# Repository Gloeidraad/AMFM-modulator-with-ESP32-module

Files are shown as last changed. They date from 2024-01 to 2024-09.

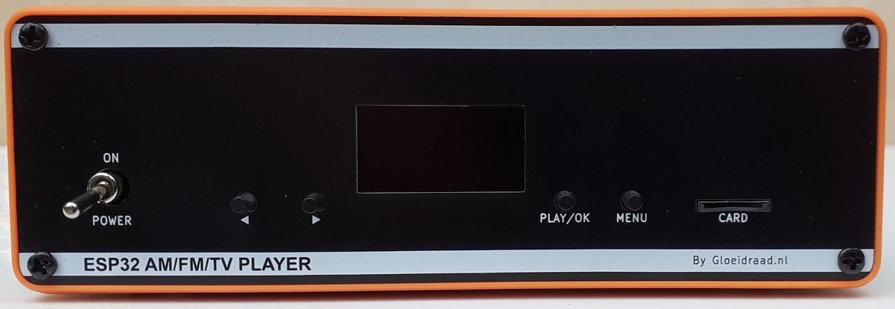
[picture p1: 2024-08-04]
V1.7/ASSY_1_7/3D-printables/Assembled 3.jpg

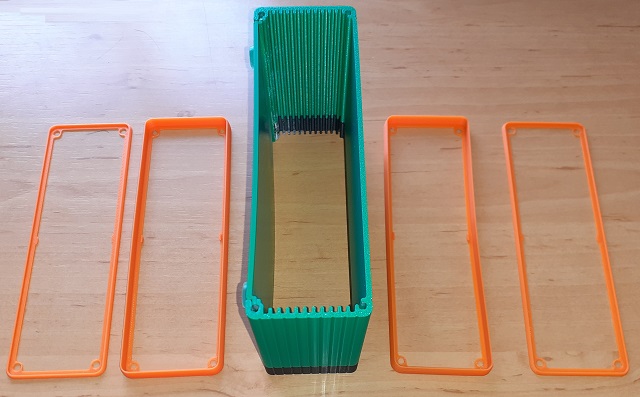
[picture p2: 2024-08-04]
V1.7/ASSY_1_7/3D-printables/Case and bezels printout.jpg

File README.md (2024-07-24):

This is an MP3 player, Web-radio player, Bluetooth player, and simple waveform generator, based on an ESP32 module. 
The output is connected to a simple FM/AM modulator. The player is intended for collectors and enthusiasts of old
(tube) radios.

The original design (V1.5) has been made with KiCad 7.0. The updated design (V1.7) has been made with KiCad 8.0.

I also added some of the specific 3D models.

Note: In many countries it is not allowed to build radio transmitters. Although this design has a range of only a 
few meters, building it is at your own risk.

Additional information can be found at: 

https://www.transistorforum.nl/forum/index.php?id=77783 and https://www.transistorforum.nl/forum/index.php?id=82213

It is in Dutch, so please use some translate program...

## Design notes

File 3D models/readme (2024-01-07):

These are some 3D models for the PCB design. They are not needed, but could be "nice to have"

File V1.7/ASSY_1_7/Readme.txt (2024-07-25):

This section contains designs for a front and back panel for the AM/FM modulator. You find them in the PlayerBack_1_7 and PlayerFront_1_7 directories. You can order the panels at a PCB supplyer or any other panel manufacturer. I recommend a panel thickness of 1 or 1.2 mm. Note that the front panel has also some electronics desing at the back side. This is not used the for player, and can be left wihtout electronic parts.

The main desing (PLL_AM_OSC_1_7_ASSY) is not intended for fabrication, but serves only as a model to show the complete design (case, PCBA, and panels).

Please unzip PLL_AM_OSC_1_7.zip in folder 3D before opening PLL_AM_OSC_1_7_ASSY.kicad_pro

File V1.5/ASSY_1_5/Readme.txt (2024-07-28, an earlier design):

This is the (unverified) design of the front panel for the V1.5 PCBA. For using this design,
you have to install the 1.3 inch OLED display on the PCBA. if you want to use the 0.96 inch
OLED display, you have to modify the viewing opening.

Please unzip PLL_AM_OSC_1_5.zip in folder 3D before opening PLL_AM_OSC_1_5_ASSY.kicad_pro

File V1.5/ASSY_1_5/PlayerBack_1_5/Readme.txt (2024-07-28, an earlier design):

You can use the bracket of V1.7. The only difference is the location of the FM telescopic antenna. 

On the V1.7 bracket, a marking has been added for the location of the V1.5 antenna.

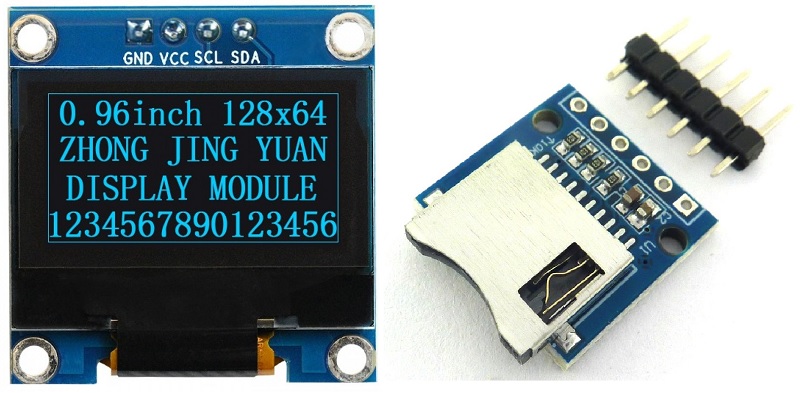
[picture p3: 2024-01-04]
images/OLED+SD.jpg

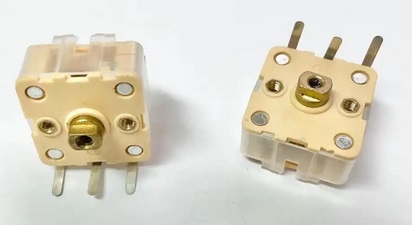
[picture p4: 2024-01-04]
images/223P.jpg

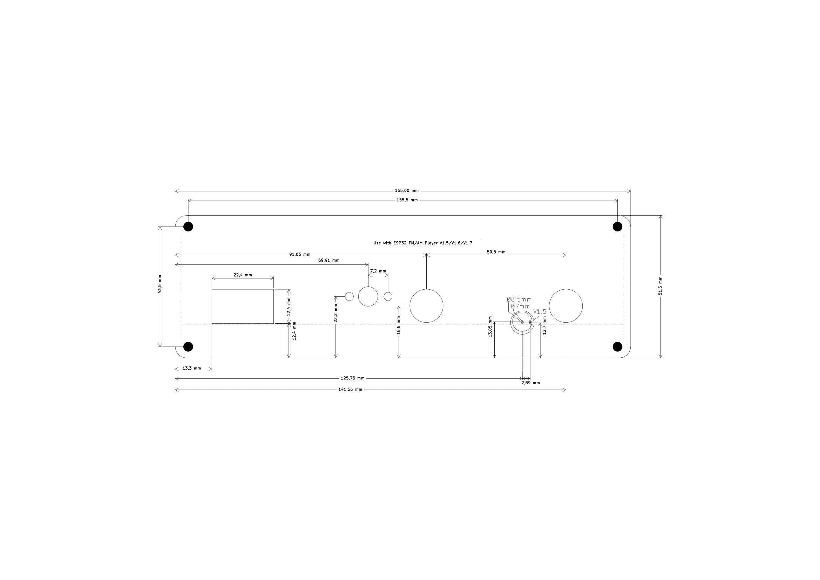
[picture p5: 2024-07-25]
V1.7/ASSY_1_7/PlayerBack_1_7/doc/PlayerBack02-dimensions.png

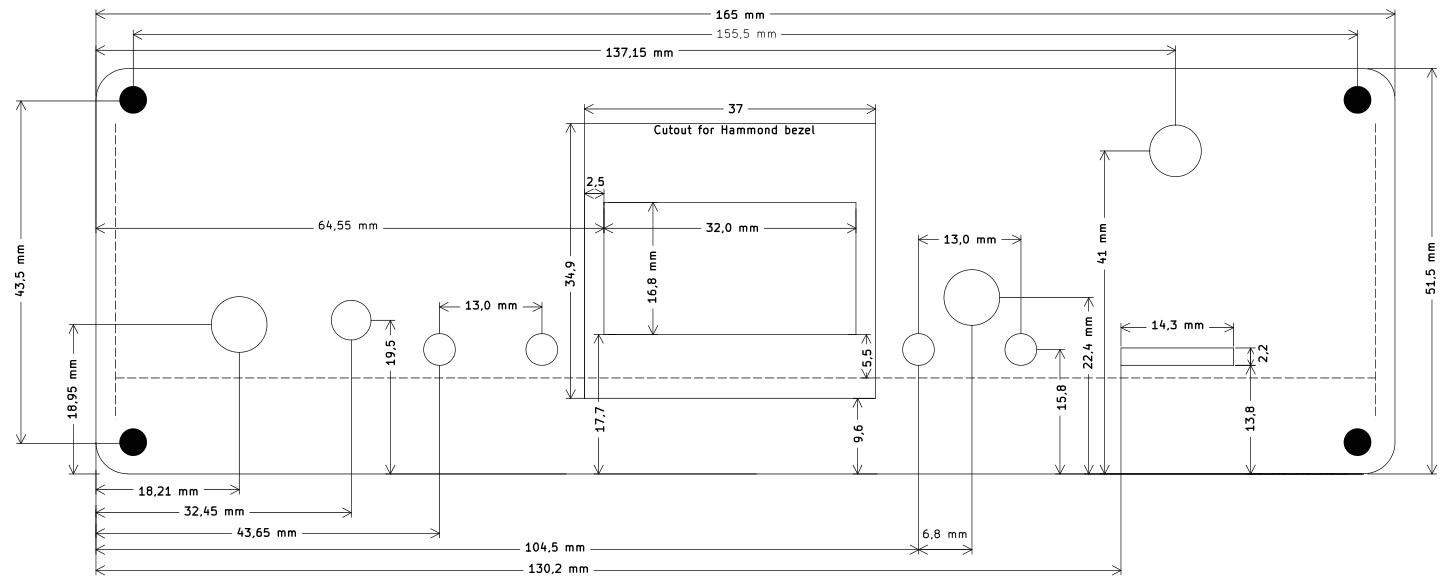
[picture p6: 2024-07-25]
V1.7/ASSY_1_7/PlayerFront_1_7/doc/PlayerFront02-dimensions.png

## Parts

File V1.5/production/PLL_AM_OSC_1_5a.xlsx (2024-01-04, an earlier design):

Item | Qty | Reference(s) | Value | DNP | Footprint / Type
1 | 3 | C1, C40, C41 | 220 µF/25V |  | Electrolytic cap, D 8mm, pitch 3.5 mm
2 | 2 | C2, C52 | 100n | DNP | Ceramic disc, pitch 5 mm
3 | 1 | C3 | 100p |  | Ceramic disc, pitch 2.5 mm
4 | 3 | C4, C54, C55 | 100n |  | MKT, pitch 5 mm
5 | 2 | C5, C25 | 47p |  | Ceramic disc, pitch 2.5 mm
6 | 1 | C6 | 27p |  | Ceramic disc, pitch 2.5 mm
7 | 1 | C7 | 470n |  | MKT, pitch 5 mm
8 | 15 | C8, C9, C10, C11, C12, C13, C19, C27, C28, C29, C36, C37, C38, C39, C48 | 100n |  | Ceramic disc, pitch 5 mm
9 | 1 | C14 | 2n2 |  | MKT, pitch 5 mm
10 | 1 | C15 | 10 µF |  | Electrolytic cap, D 6.3mm, pitch 2.5 mm
11 | 1 | C16 | 10n |  | MKT, pitch 5 mm
12 | 1 | C17 | 120p |  | -
13 | 1 | C18 | 100 µF |  | Electrolytic cap, D 8mm, pitch 3.5 mm
14 | 2 | C20, C22 | 1n |  | MKT, pitch 5 mm
15 | 2 | C21, C23 | 470p |  | MKT, pitch 5 mm
16 | 1 | C24 | 10n |  | Ceramic disc, pitch 2.5 mm
17 | 3 | C26, C46, C47 | 15p |  | Ceramic disc, pitch 2.5 mm
18 | 4 | C30, C31, C32, C33 | 22n |  | MKT, pitch 5 mm
19 | 1 | C34 | 120p | DNP | -
20 | 1 | C35 | 142+59 pF | DNP | Variable capacitor type 223P
21 | 1 | C42 | 1000 µF/35V |  | Electrolytic cap, D 13mm, pitch 5 mm
22 | 1 | C43 | 2200 µF/16V |  | Electrolytic cap, D 13mm, pitch 5 mm
23 | 2 | C44, C45 | 4n7/Y1 |  | Ceramic disc pitch 10 mm
24 | 3 | C49, C50, C51 | 10n | DNP | Ceramic disc, pitch 2.5 mm
25 | 1 | C53 | 10u | DNP | Electrolytic cap, D 6.3mm, pitch 2.5 mm
26 | 1 | C58 | 4p7 |  | Ceramic disc, pitch 2.5 mm
27 | 2 | C59, C60 | 220p |  | Ceramic disc, pitch 2.5 mm
28 | 1 | D1 | Bridge rectifier 1A |  | DIL 4
29 | 2 | D2, D3 | 1N4001 |  | -
30 | 2 | D4, D5 | BAT85 |  | DO-35/SOD27
31 | 1 | E1 | ANTENNA | DNP | Telescopic antenna
32 | 4 | H1, H2, H3, H4 | MountingHole | DNP | n.a.
33 | 1 | J1 | 230V~ |  | IEC 60320 C8 AC Power Socket 2 pin PCB Mount
34 | 1 | J2 | Conn_01x03 | DNP | PinHeader 2.54mm male
35 | 2 | J4, J5 | Keystone 900 |  | Keystone RCA ot similar
36 | 3 | JP1, JP7, JP9 | SolderJumper_3_Bridged12 | DNP | -
37 | 1 | JP2 | LSEL |  | PinHeader 2.54mm male
38 | 1 | JP3 | SolderJumper_3_Bridged12 | DNP | -
39 | 4 | JP4, JP5, JP6, JP8 | SolderJumper_3_Bridged12 | DNP | -
40 | 2 | L1, L2 | 330 µH |  | Axial
41 | 2 | L3, L4 | 180 µH |  | Axial
42 | 1 | L5 | 120nH | DNP | SMD 0805
43 | 1 | M1 | ESP32-WROVER-CAM |  | Placed on 2 PinHeaders 2.54mm female 20 positions
44 | 1 | M2 | µSD CARD MODULE |  | Soldered on PinHeader 2.54mm male
45 | 1 | M3 | ELECHOUSE FM TRANSMITTER V2.0 | DNP | Soldered on PinHeaders 2.54mm male
46 | 1 | M4 | OLED-27X27MM |  | Including PinHeader 2.54mm male
47 | 1 | M5 | Hi-Link HLK-5M15 | DNP | -
48 | 1 | M6 | CN3903 5V/3A Module | DNP | -
49 | 3 | Q1, Q2, Q3 | 2N7000 |  | TO-92
50 | 12 | R1, R2, R3, R4, R5, R27, R30, R39, R41, R42, R43, R44 | 10k |  | Axial 1/4 watt
51 | 1 | R6 | 100k | DNP | Axial 1/4 watt
52 | 2 | R7, R8 | 10k | DNP | Axial 1/4 watt
53 | 1 | R10 | 10R |  | Axial 1/4 watt
54 | 6 | R12, R13, R14, R15, R35, R36 | 7k5 |  | Axial 1/4 watt
55 | 4 | R16, R17, R18, R31 | 30k |  | Axial 1/4 watt
56 | 1 | R19 | 220K |  | Axial 1/4 watt
57 | 2 | R20, R21 | 1M |  | Axial 1/4 watt
58 | 1 | R22 | 2K2 |  | Axial 1/4 watt
59 | 1 | R23 | 100K |  | Axial 1/4 watt
60 | 1 | R24 | 3K3 |  | Axial 1/4 watt
61 | 1 | R25 | 2M2 |  | Axial 1/4 watt
62 | 1 | R26 | 5K6 |  | Axial 1/4 watt
63 | 3 | R28, R29, R40 | 220R |  | Axial 1/4 watt
64 | 1 | R32 | 8k2 |  | Axial 1/4 watt
65 | 2 | R33, R34 | 4K7 |  | Axial 1/4 watt
66 | 1 | R37 | 15k |  | Axial 1/4 watt
67 | 1 | R46 | 10R | DNP | Axial 1/4 watt
68 | 3 | SH1, SH2, SH3 | Shield |  | n.a.
69 | 1 | SW1 | DOWN |  | Tactile SPST Angled PTS645Vx83
70 | 1 | SW2 | UP |  | Tactile SPST Angled PTS645Vx83
71 | 1 | SW3 | PAUSE/OK |  | Tactile SPST Angled PTS645Vx83
72 | 1 | SW4 | MENU |  | Tactile SPST Angled PTS645Vx83
73 | 1 | SW5 | SW_SPDT |  | SWITCH C&K 7101 or similar
74 | 1 | SW7 | Rotary Encoder with Switch | DNP | -
75 | 3 | TP1, TP2, TP3 | TestPoint | DNP | n.a.
76 | 1 | TR1 | 2x7.5V/3.2VA |  | Gerth 387.15.2
77 | 1 | U1 | CD4053B |  | DIP-16
78 | 1 | U2 | CD4060B |  | DIP-16
79 | 1 | U3 | CD4046B |  | DIP-16
80 | 1 | U4 | CD40103B |  | DIP-16
81 | 1 | U5 | 24LC64 |  | DIP-8 or SOIC-8
82 | 1 | U6 | PT8211 |  | SOIC-8 or DIP-8
83 | 1 | U7 | 7805 |  | TO-220 with metal tab
84 | 1 | U8 | 7815 |  | TO-220 with metal tab
85 | 1 | U9 | CD4015B |  | DIP-16
86 | 2 | U10,U11 | LM358 |  | DIP-8 or SOIC-8
87 | 1 | U12 | KT0803L |  | SOIC-16
88 | 1 | U13 | TSOP4538 | DNP | Vishay TSOP4538
89 | 1 | X1 | 9.216 MHz |  | Crystal HC49
90 | 1 | X2 | 32.768kHz |  | Crystal AT310

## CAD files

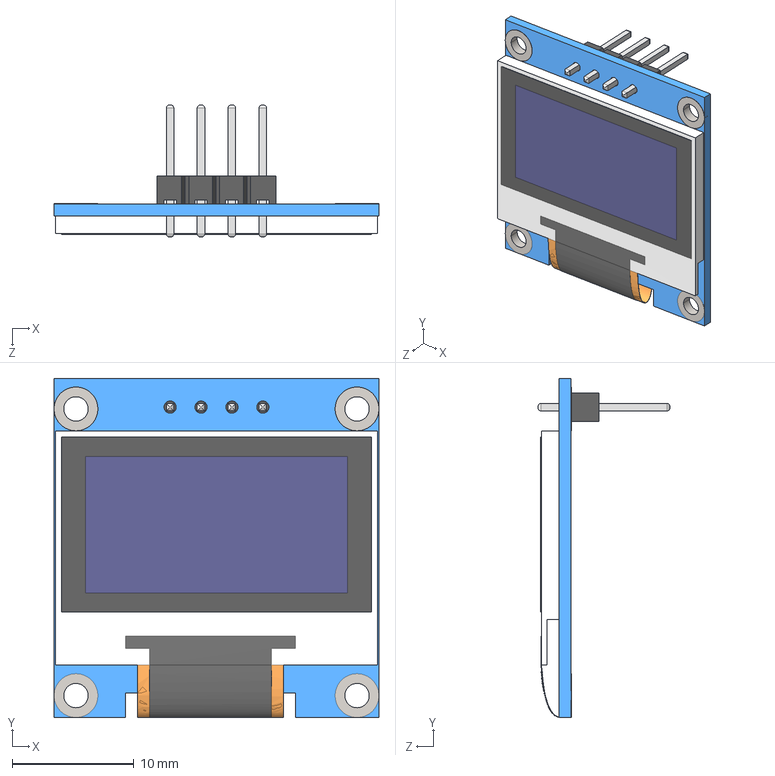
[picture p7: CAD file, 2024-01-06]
3D models/User Library-128x64I2COLEDDisplayAdafruit.step
26.7 x 27.9 x 10.8 mm

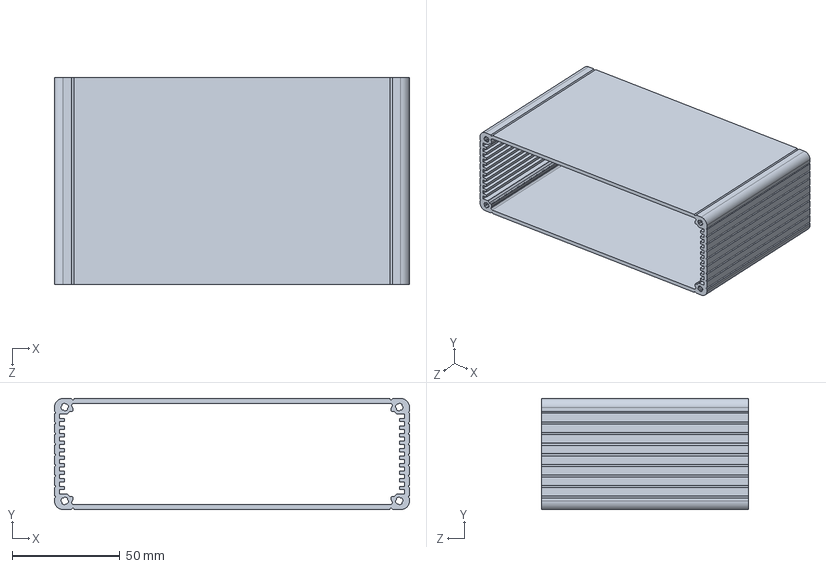
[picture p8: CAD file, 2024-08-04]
V1.7/ASSY_1_7/3D-printables/Case Body-96mm.STEP
165.0 x 51.6 x 96.0 mm

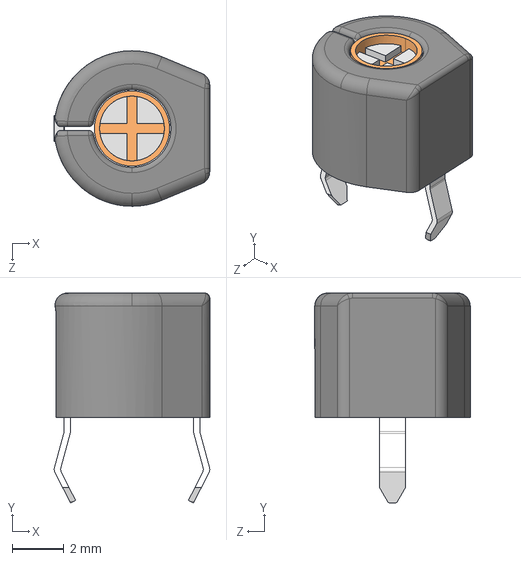
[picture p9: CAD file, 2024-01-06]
3D models/Trimmer-Murata-TZ03.step
6.00 x 8.10 x 6.00 mm

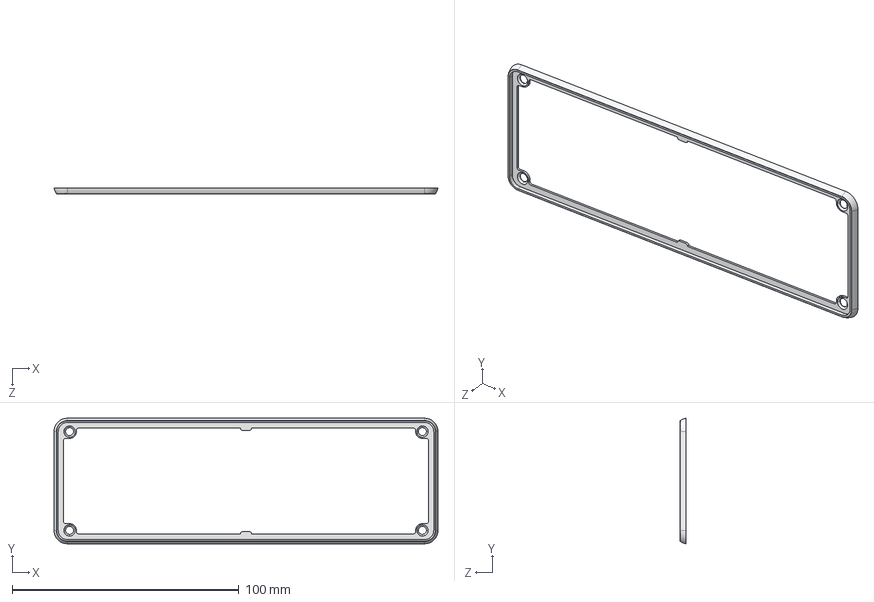
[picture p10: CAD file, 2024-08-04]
V1.7/ASSY_1_7/3D-printables/Case Bezel Outer Half.STEP
169.2 x 55.4 x 2.60 mm

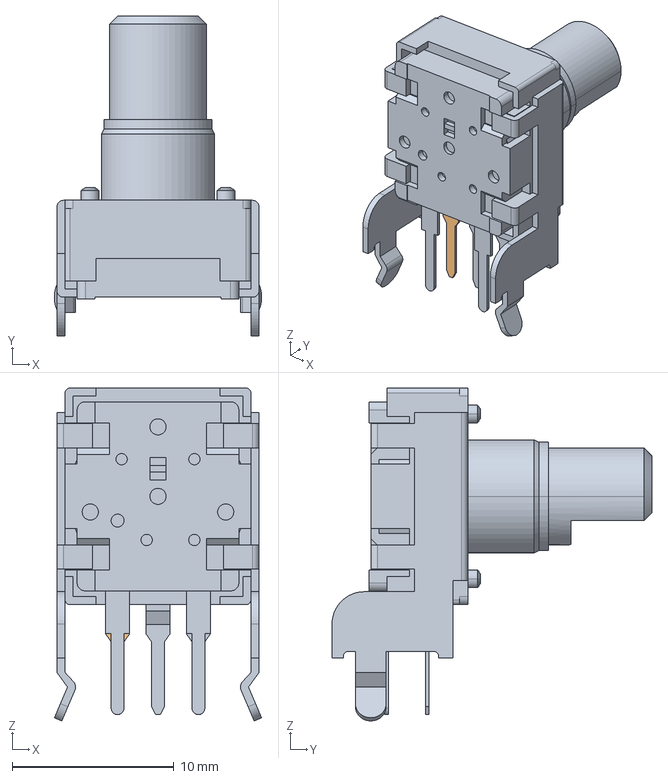
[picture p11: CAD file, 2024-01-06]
3D models/pec12r-2x17f-sxxxx.stp
12.8 x 19.8 x 20.6 mm

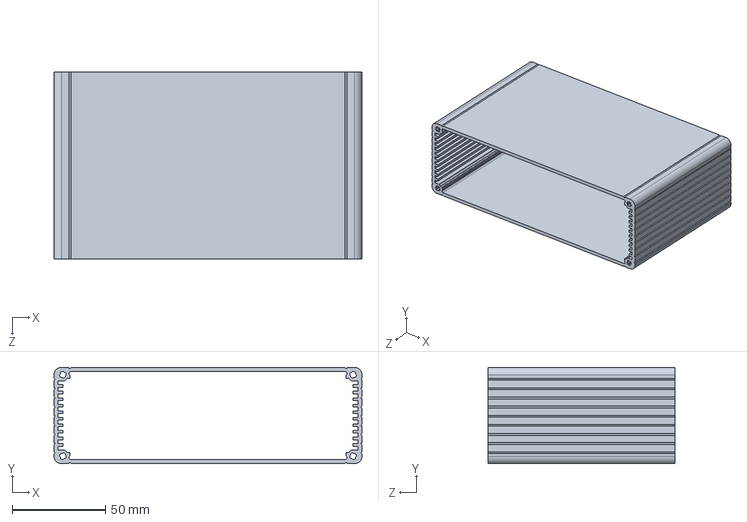
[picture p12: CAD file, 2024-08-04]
V1.7/ASSY_1_7/3D-printables/Case Body-100mm.STEP
165.0 x 51.6 x 100.0 mm

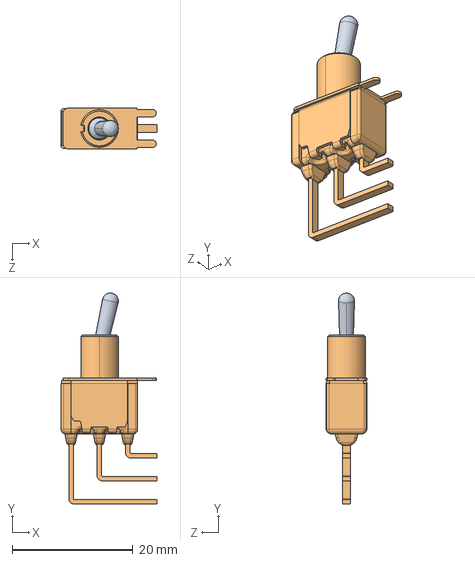
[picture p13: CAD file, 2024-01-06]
3D models/User Library-C_k_7101MD9AV2BE.STEP
15.9 x 35.0 x 6.76 mm

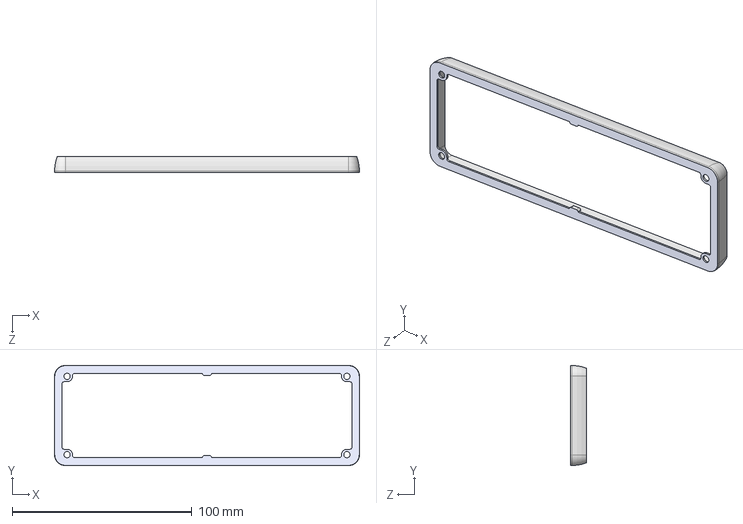
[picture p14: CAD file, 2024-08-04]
V1.7/ASSY_1_7/3D-printables/Case Bezel Inner Half.STEP
169.5 x 55.6 x 8.90 mm

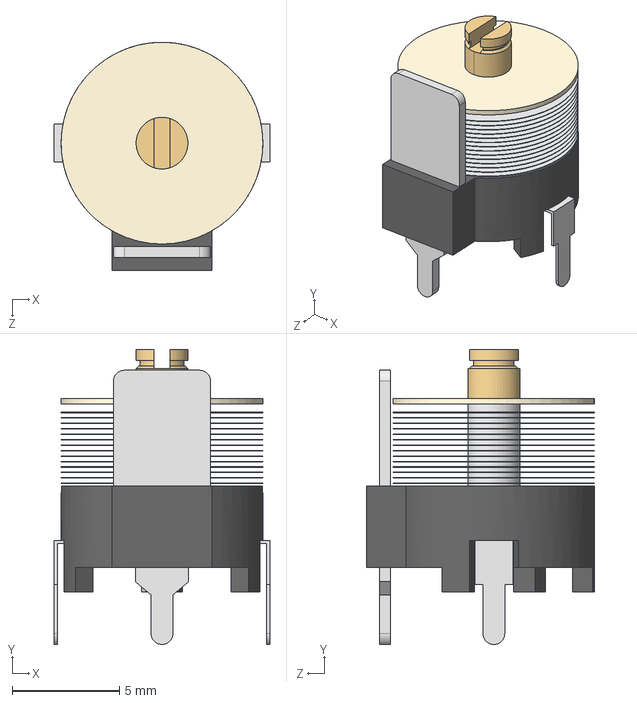
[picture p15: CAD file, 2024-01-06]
3D models/Folietrimmer-type1.step
10.1 x 13.7 x 10.6 mm

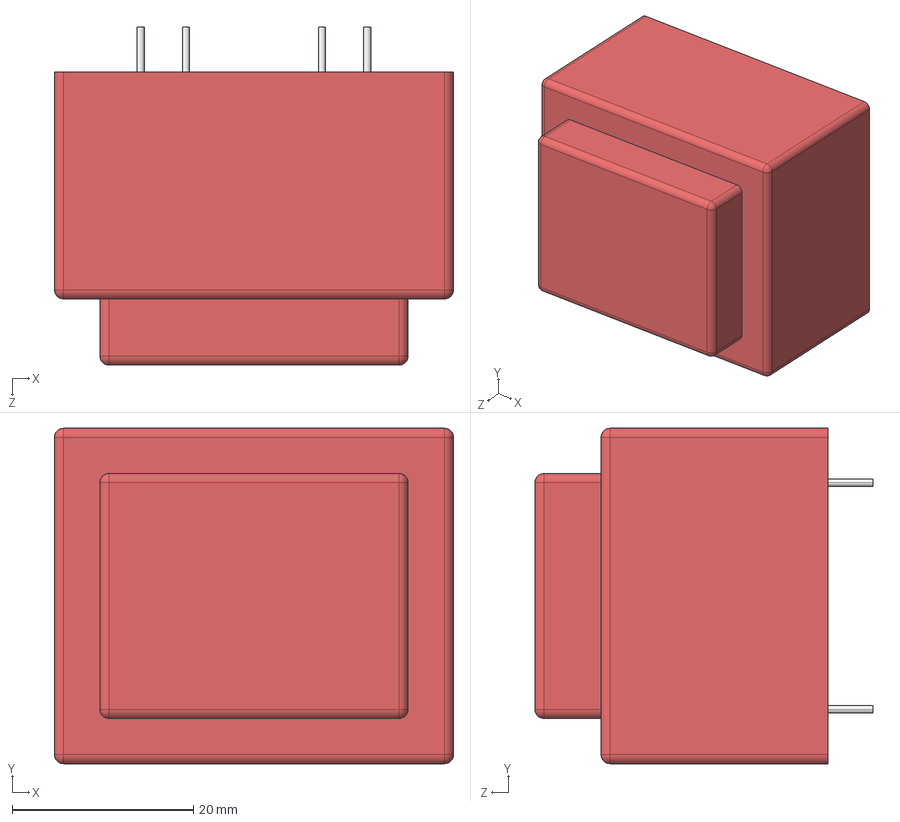
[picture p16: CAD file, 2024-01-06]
3D models/Transformer-DS44234.STEP
44.0 x 37.0 x 37.3 mm

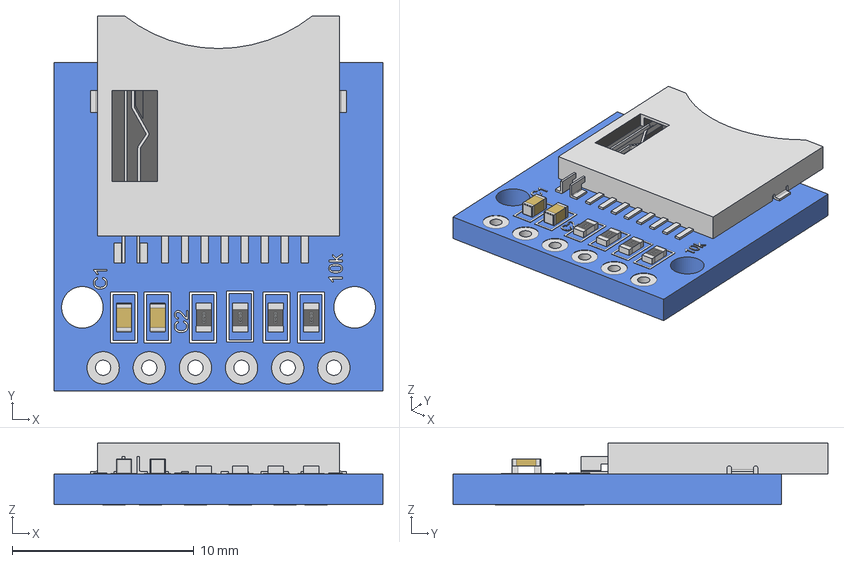
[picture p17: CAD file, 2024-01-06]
3D models/MicroSD Card Module-1.stp
18.1 x 20.6 x 3.40 mm
Micro SD Module - 1
MicroSD
0603 Capacitor x 2
0603 Resistor x 4

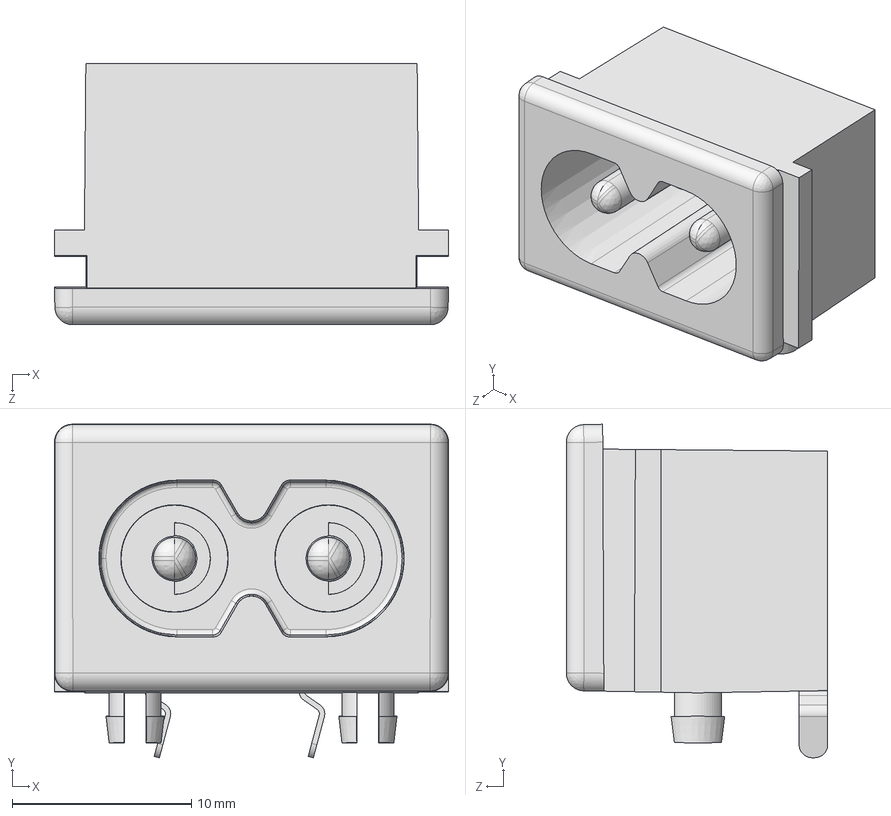
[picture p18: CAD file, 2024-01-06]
3D models/E_2750-2210_03new.STEP
22.0 x 18.6 x 14.6 mm

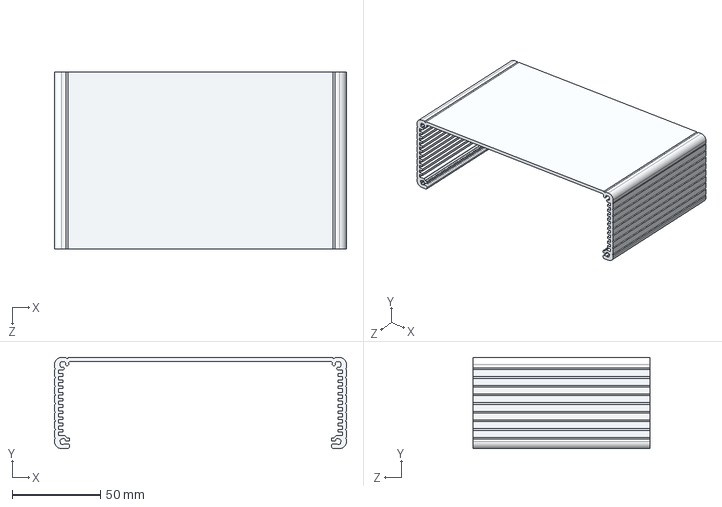
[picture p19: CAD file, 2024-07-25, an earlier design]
V1.5/ASSY_1_5/3D/1455T2202-base-100mm.STEP
165.0 x 51.5 x 100.0 mm

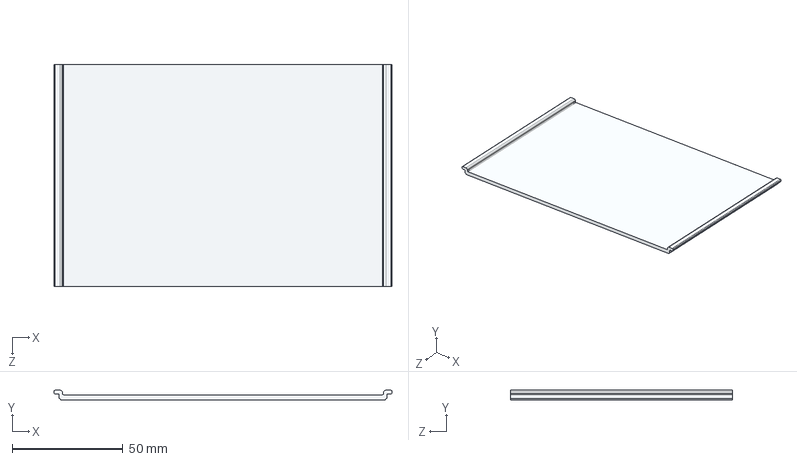
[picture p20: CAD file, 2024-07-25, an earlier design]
V1.5/ASSY_1_5/3D/1455T2202-top-100mm.STEP
152.4 x 4.29 x 100.0 mm

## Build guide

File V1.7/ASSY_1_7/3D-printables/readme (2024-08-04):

Here you find some STEP files for 3D printing your own housing for the ESP32 Player. 
There are two options:

1 - Just print "Case Body-100mm.STEP" for a simple housing.
2 - "Print Case Body-96mm.STEP", two times "Case Bezel Outer Half.STEP", and two times "Case Bezel Inner Half.STEP"

Option 2 gives you a nicer finish, but need more work. In addition you can customize your housing by using different colors
for the body and the bezels. There are some images included to give you an impression.

Both versions still need front and back panels.

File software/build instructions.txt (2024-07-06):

This sketch has been built with Arduino IDE 2.3.2 and ESP32 board package 2.0.17.

It should be no problem to use a newer or older IDE version, however these
instructions are for the 2.3.2 version. However, the sketch will not run
when compiled with ESP32 board package 3.0.0 or higher.

Step 1: Download the Arduino IDE software from:
        https://www.arduino.cc/en/software
        (Possibly scroll down on the page for 2.3.2)
 
Step 2: Open Arduino IDE and install the ESP32 packages:
        https://randomnerdtutorials.com/installing-the-esp32-board-in-arduino-ide-windows-instructions/
        (Remark: the few seconds they mentioned to install the
        package is actually a couple of minutes, so be patient)

Step 3: Download the sketch, and make sure the whole
        project is inside the directory ESP32-AM-FM-Modulator
        Open the directory and open project ESP32-AM-FM-Modulator.ino
        
Step 4: Select the target board with menu:
        Tools => Board "xxx" => ESP32 Arduino => ESP32 WROVER Module
        
Step 5: Select the needed partition scheme with menu:
        Tools => Partition Scheme "xxx" => Huge APP (...)
        
Step 6: Switch on both “Show verbose output” checkboxes in menu:
        File => Preferences => tab Settings
        (Building the sketch takes a long time, so it is useful
        to monitor the progress)
        
Step 7: Connect the USB cable to the ESP32 module and make sure that
        the PC recognizes it as a serial port. If not, install the
        drivers for the corresponding serial adapter, normally
        CP2102,r CH340C, or CH9102
         
Step 8: Choose the port of the ESP32 module via menu:
        Tools => Port
         
Step 9: To see the debug info, you can open a serial monitor:
        Tools => Serial Monitor
        And set the baud rate to 115200
         
Step 10: Compile and upload the sketch:
         Sketch => Upload (or press the (->) button)
         It will take a while to compile the whole sketch,
         so have a little patience...
         
Step 11: You can monitor the messages from the sketch in the serial
         monitor, as long as the USB cable is connected. In addition,
         you can query some information by sending some simple commands.
         Send a ? to get a list of the commands.

Notes:

I used the following libaries for the project: 
 
https://github.com/schreibfaul1/ESP32-audioI2S/
https://github.com/pschatzmann/ESP32-A2DP
https://github.com/mathertel/OneButton

I included those used directories directly in the project. In the previous version
the libraries were installed separately, but it appeared that using a newer or older
version of the library can lead to errors or unwanted behavior. Therefore, working
versions are included in the project (in subdirectory “src”). Please take care if
you plan to replace them with a different version.
          
Please report if you encounter any problems with the libraries.

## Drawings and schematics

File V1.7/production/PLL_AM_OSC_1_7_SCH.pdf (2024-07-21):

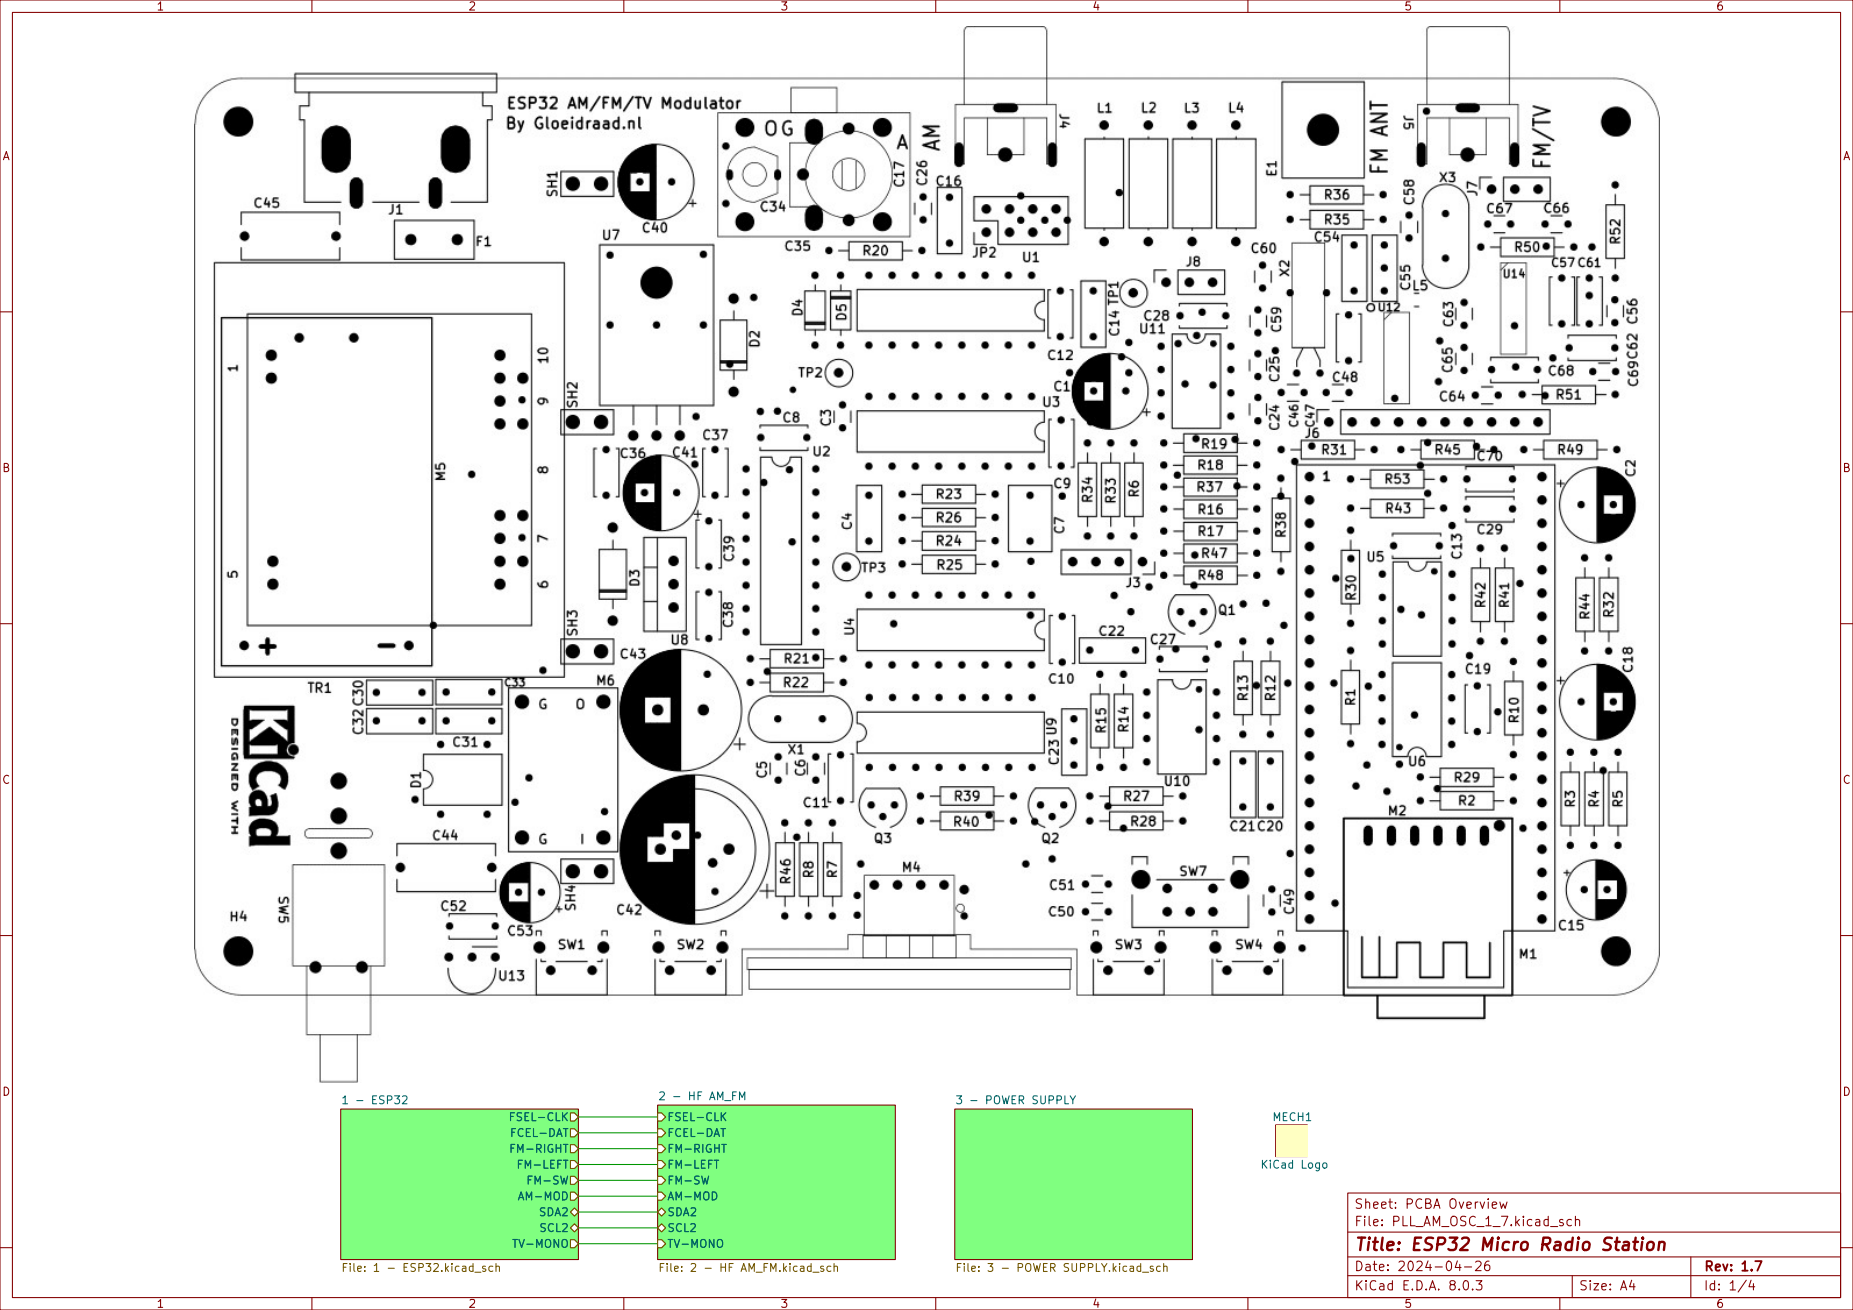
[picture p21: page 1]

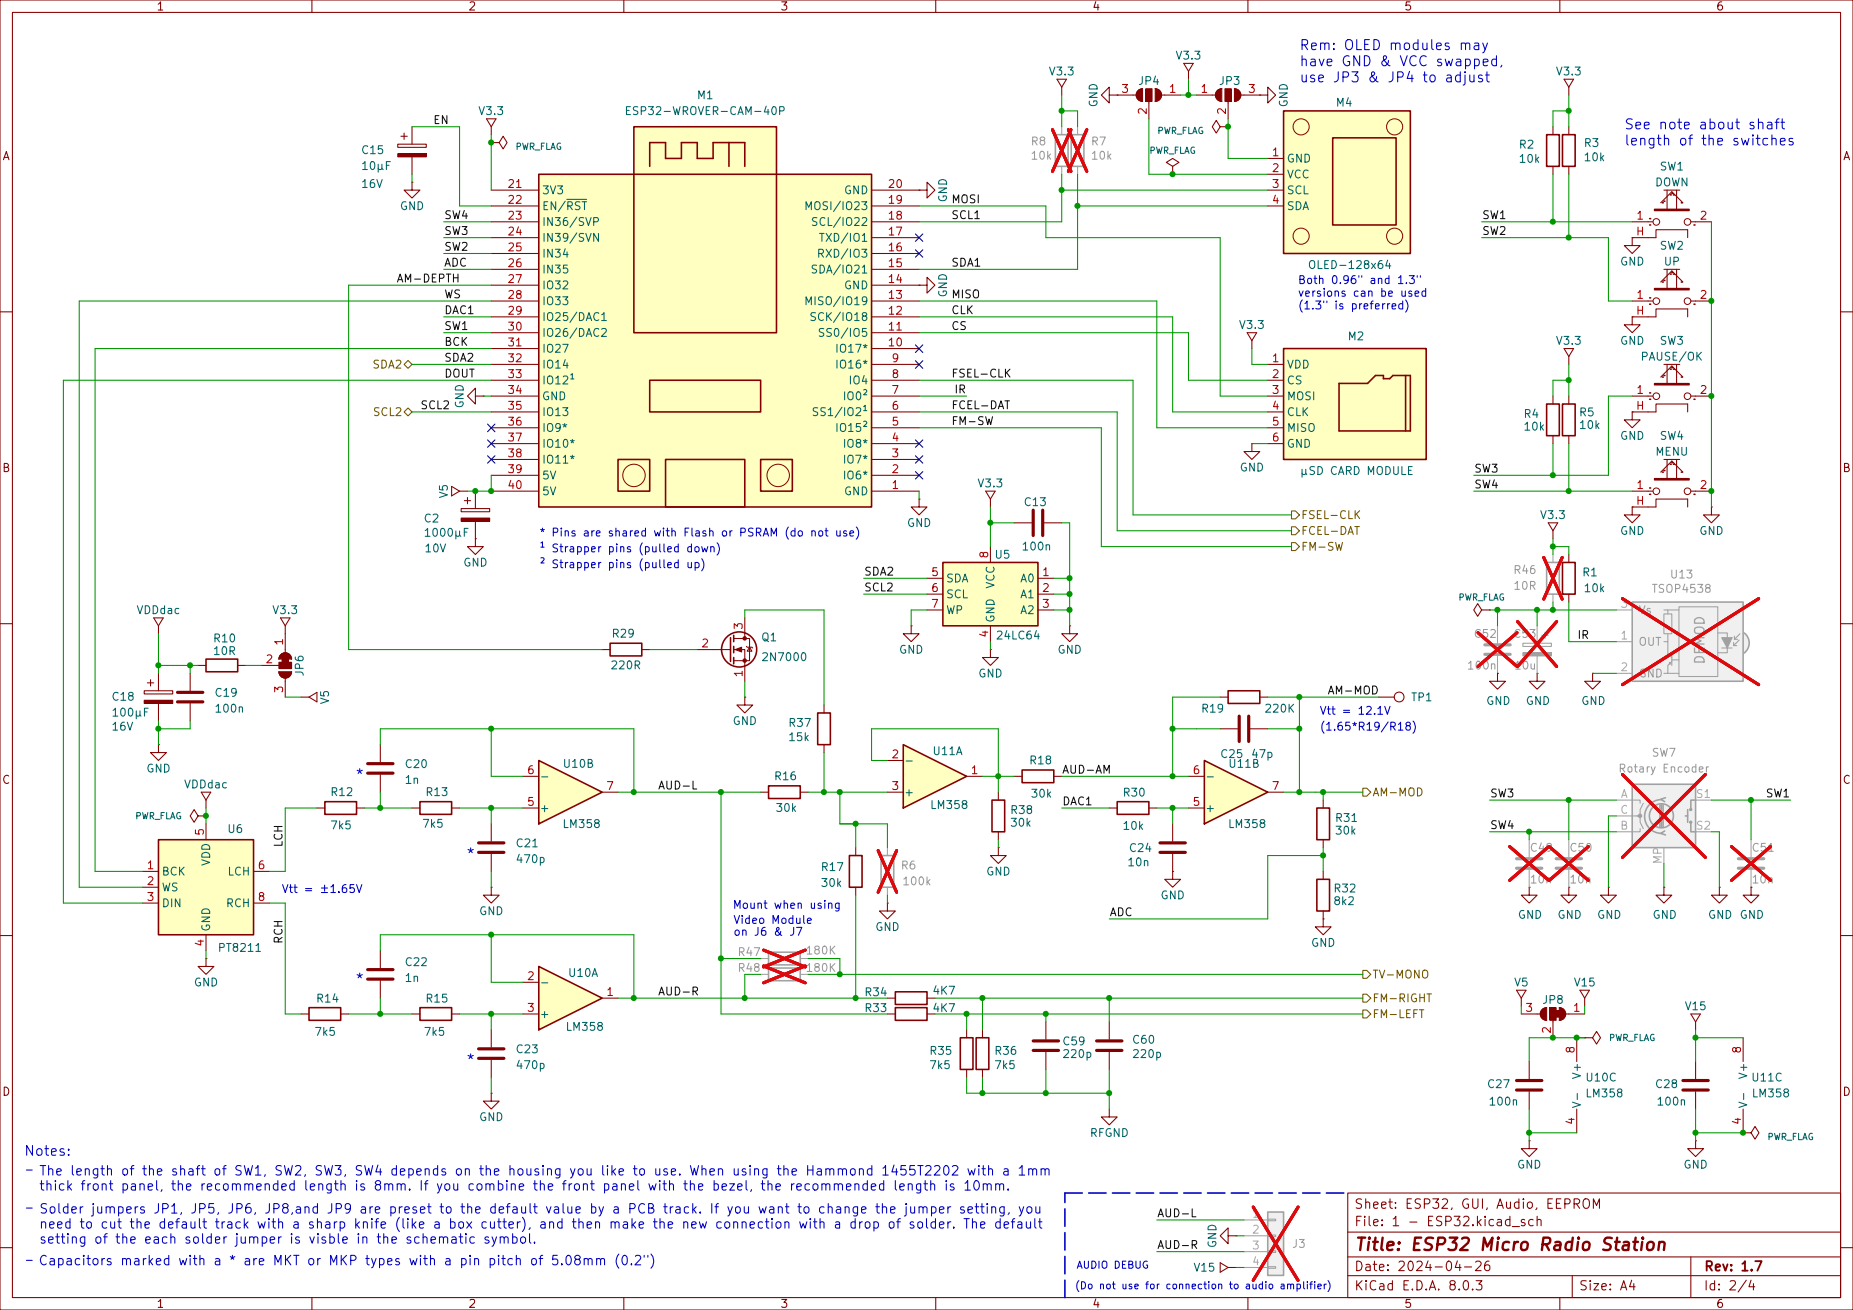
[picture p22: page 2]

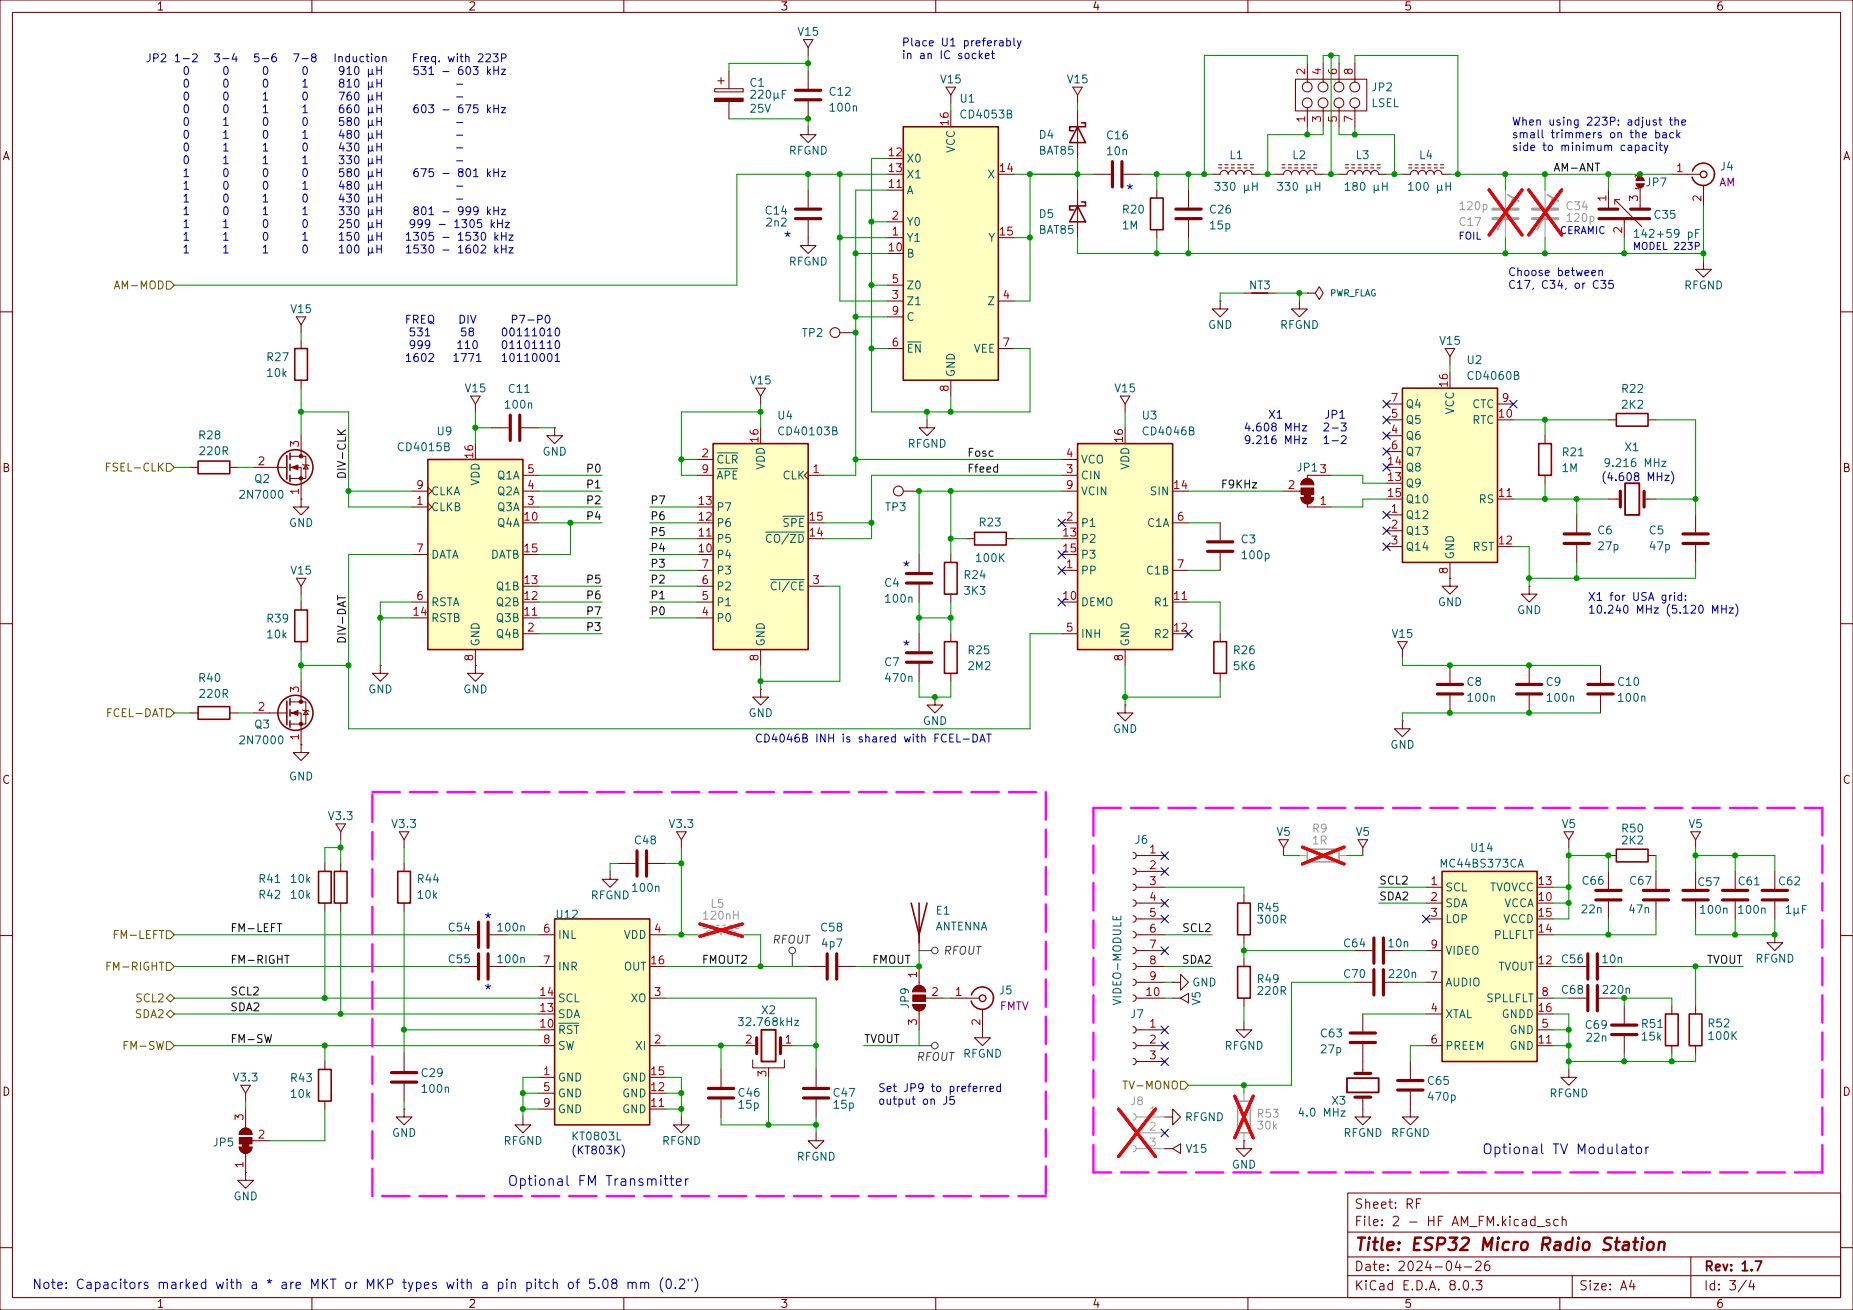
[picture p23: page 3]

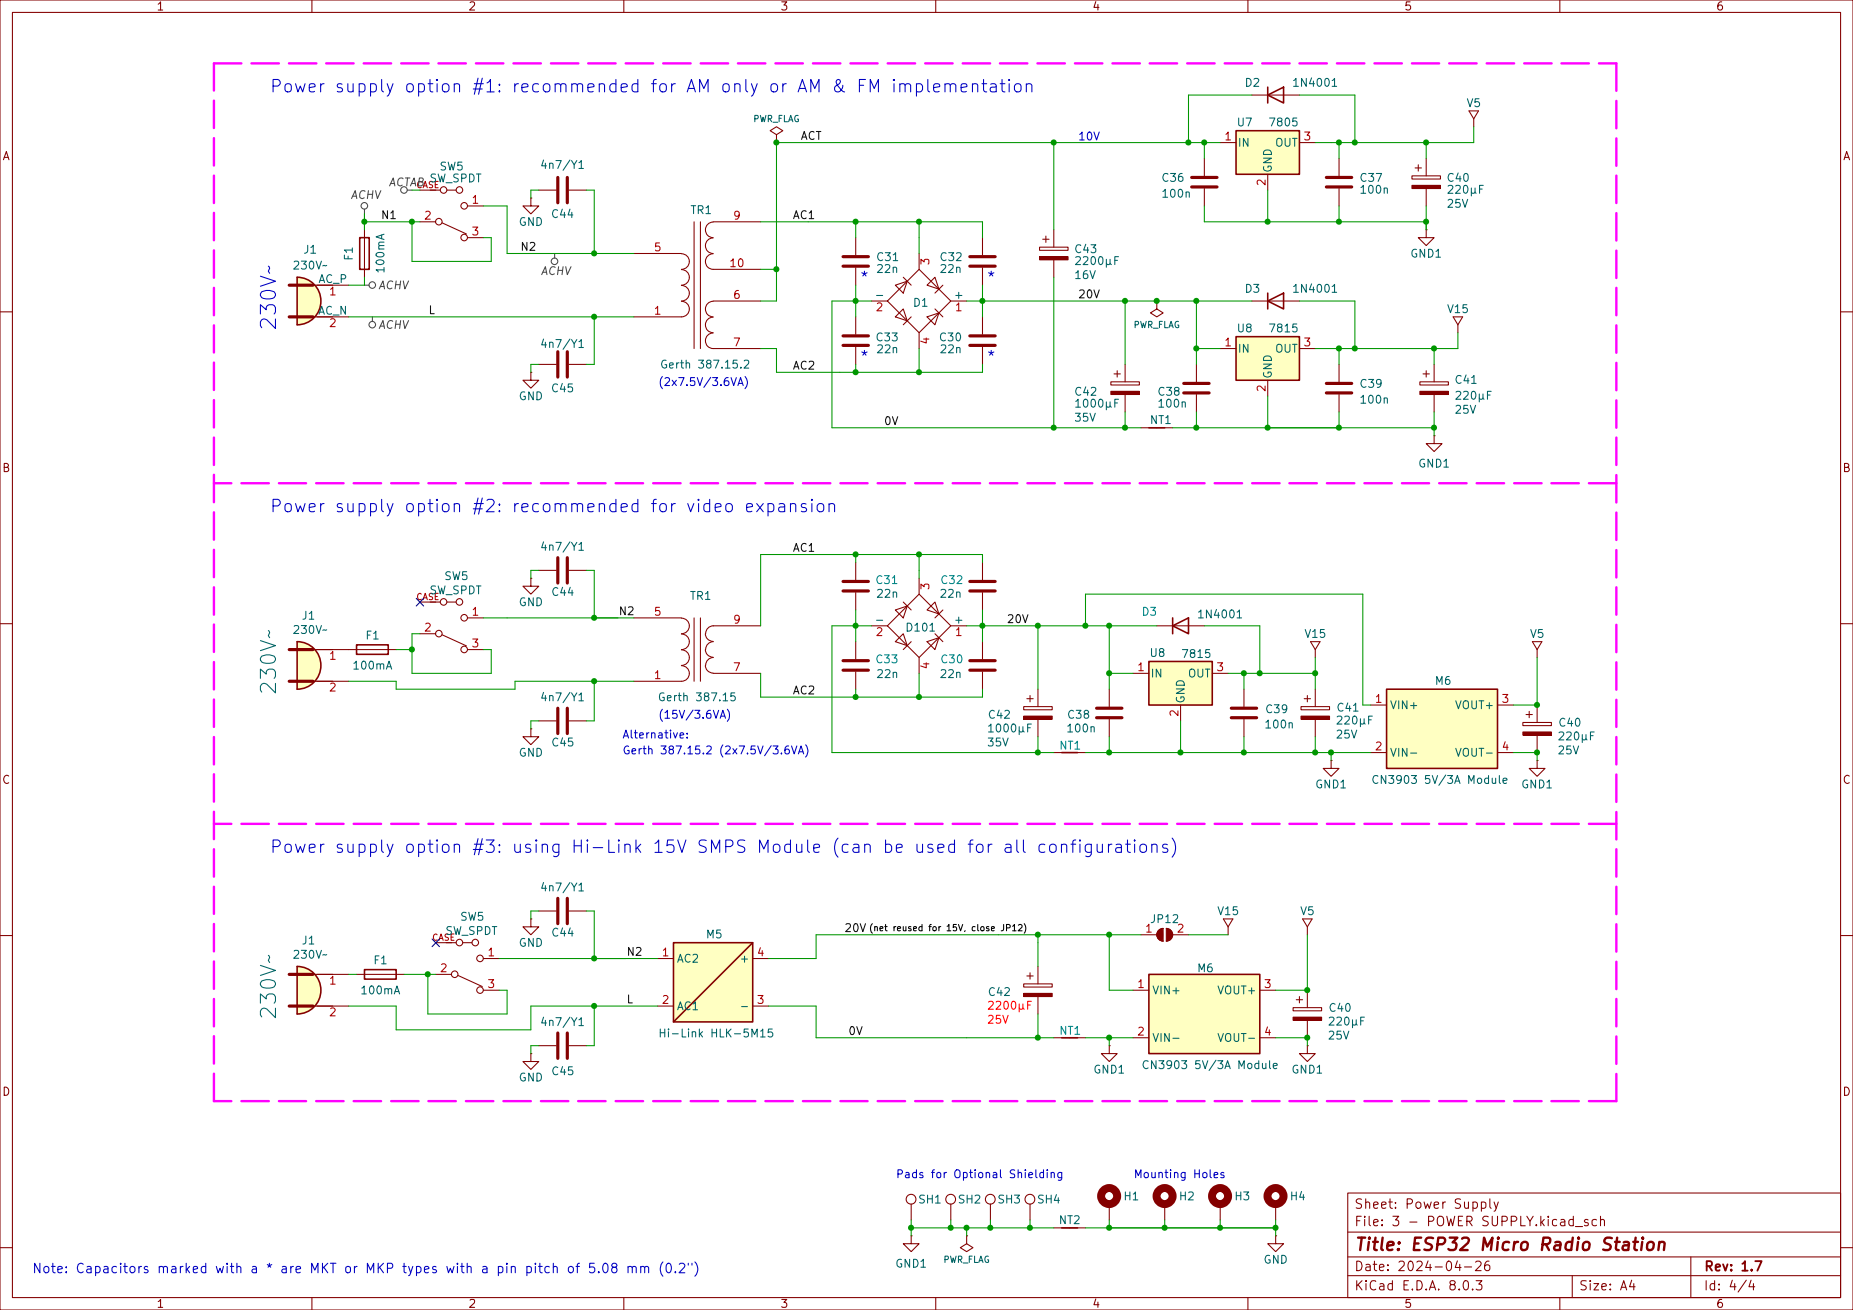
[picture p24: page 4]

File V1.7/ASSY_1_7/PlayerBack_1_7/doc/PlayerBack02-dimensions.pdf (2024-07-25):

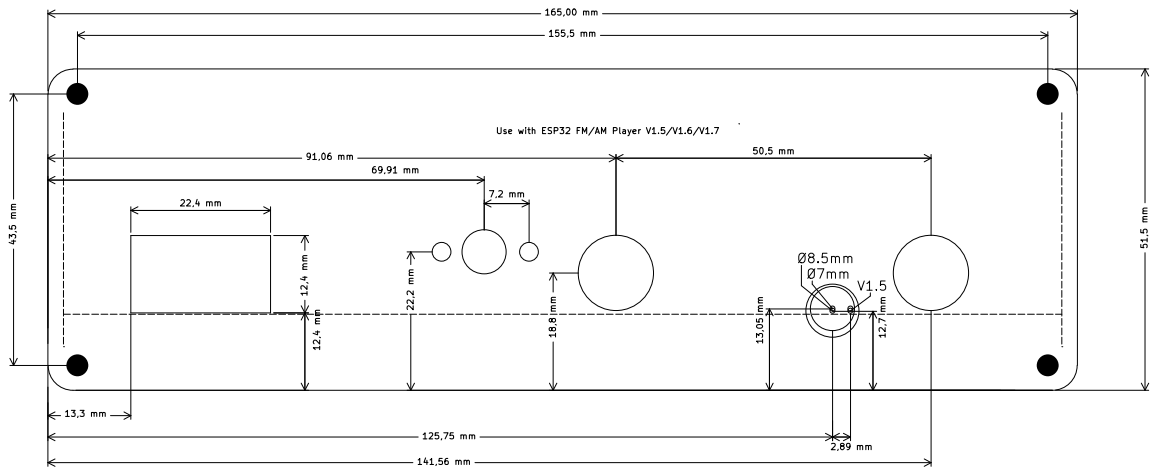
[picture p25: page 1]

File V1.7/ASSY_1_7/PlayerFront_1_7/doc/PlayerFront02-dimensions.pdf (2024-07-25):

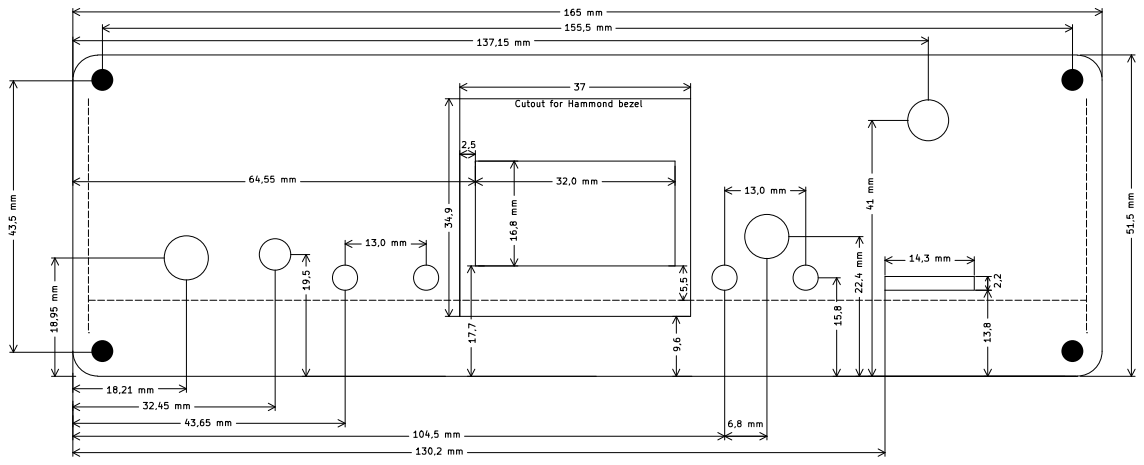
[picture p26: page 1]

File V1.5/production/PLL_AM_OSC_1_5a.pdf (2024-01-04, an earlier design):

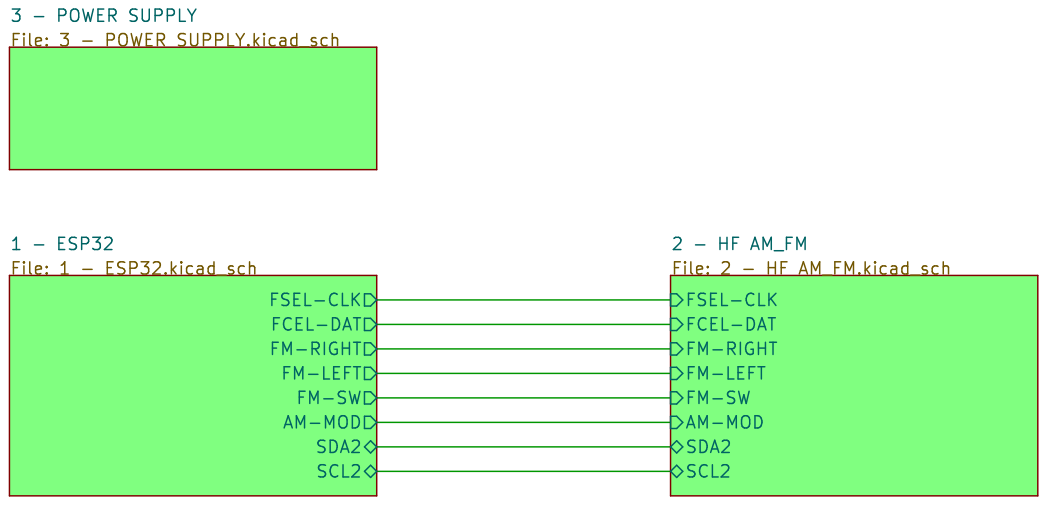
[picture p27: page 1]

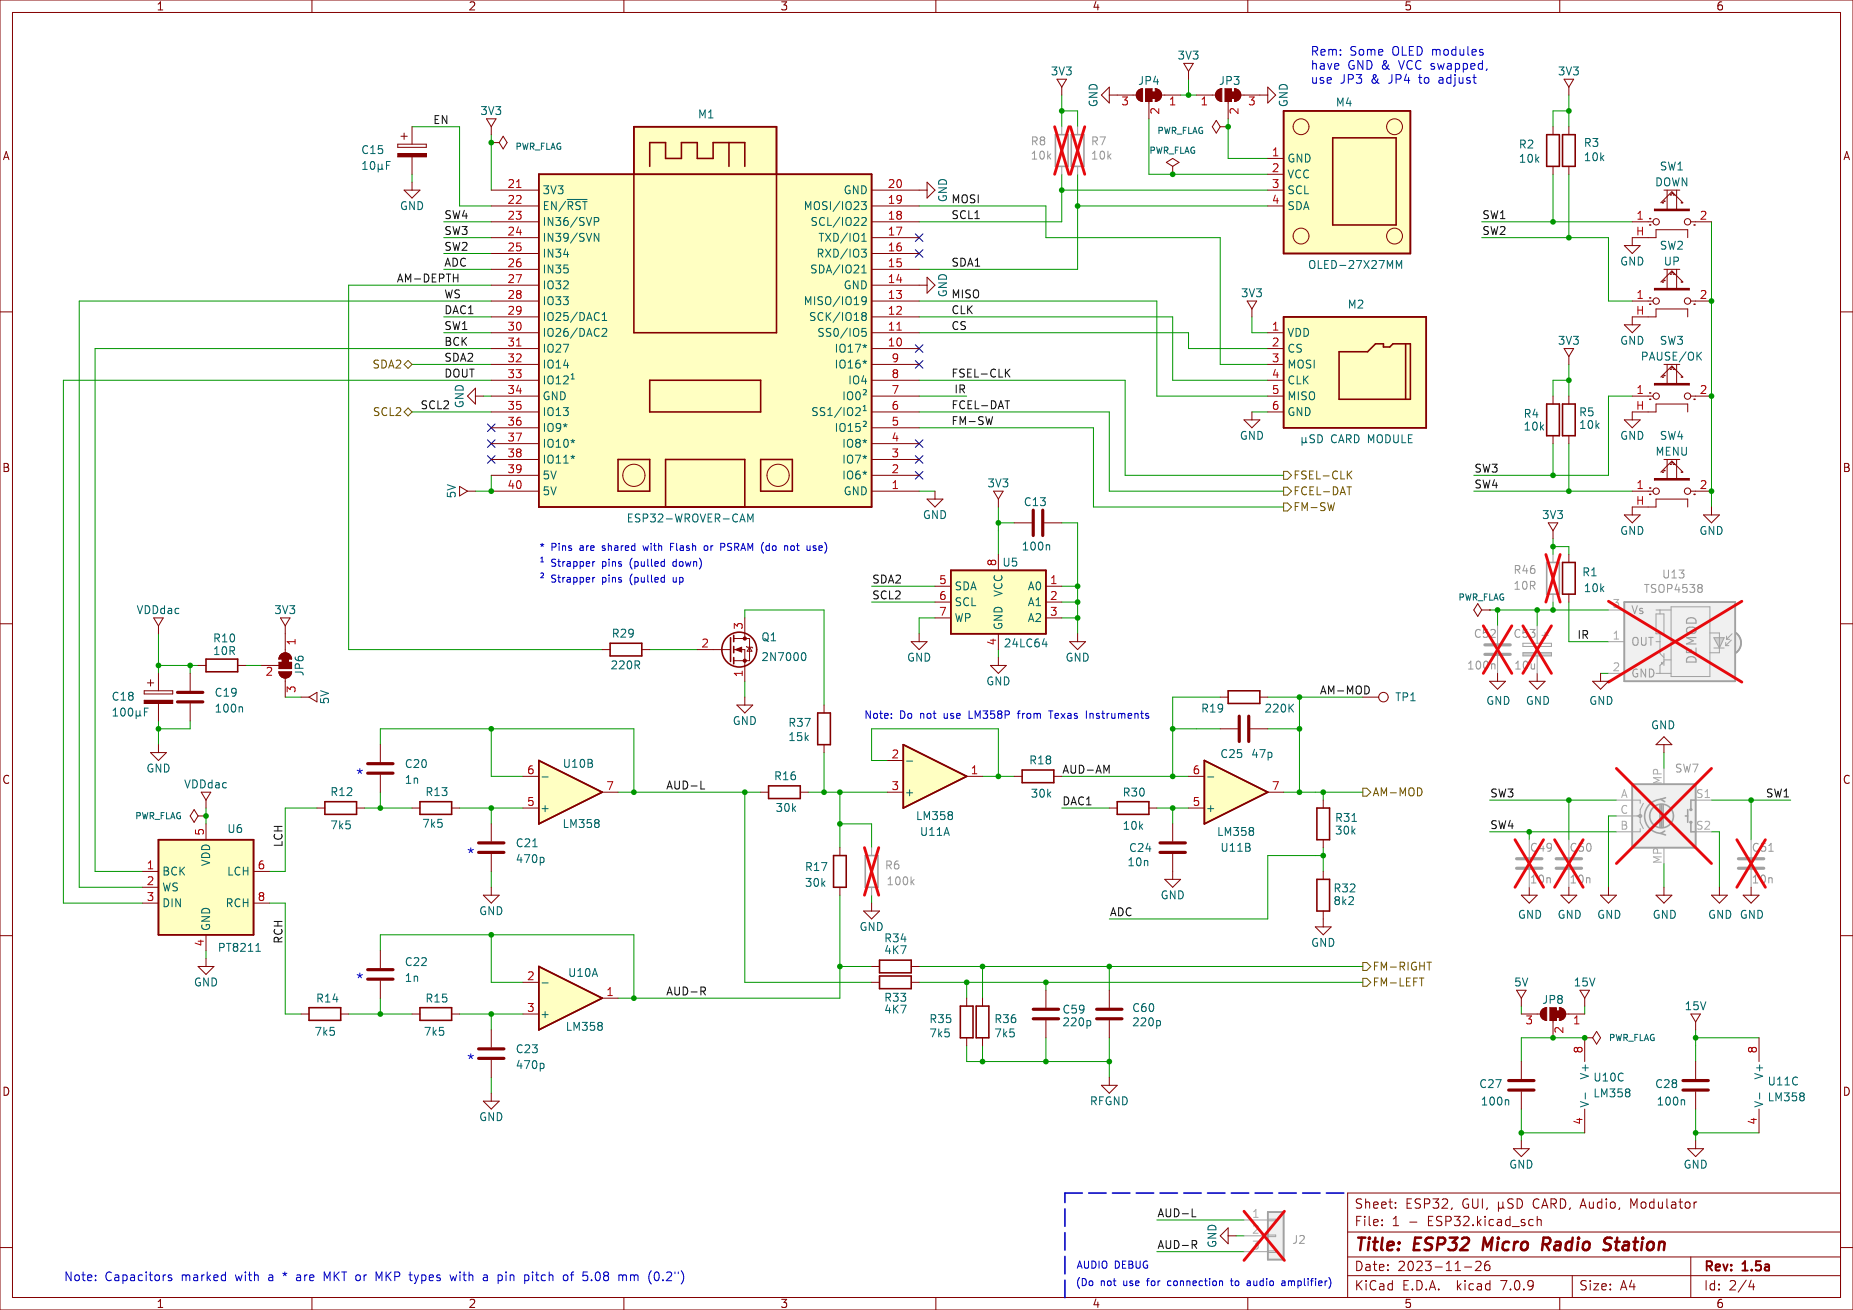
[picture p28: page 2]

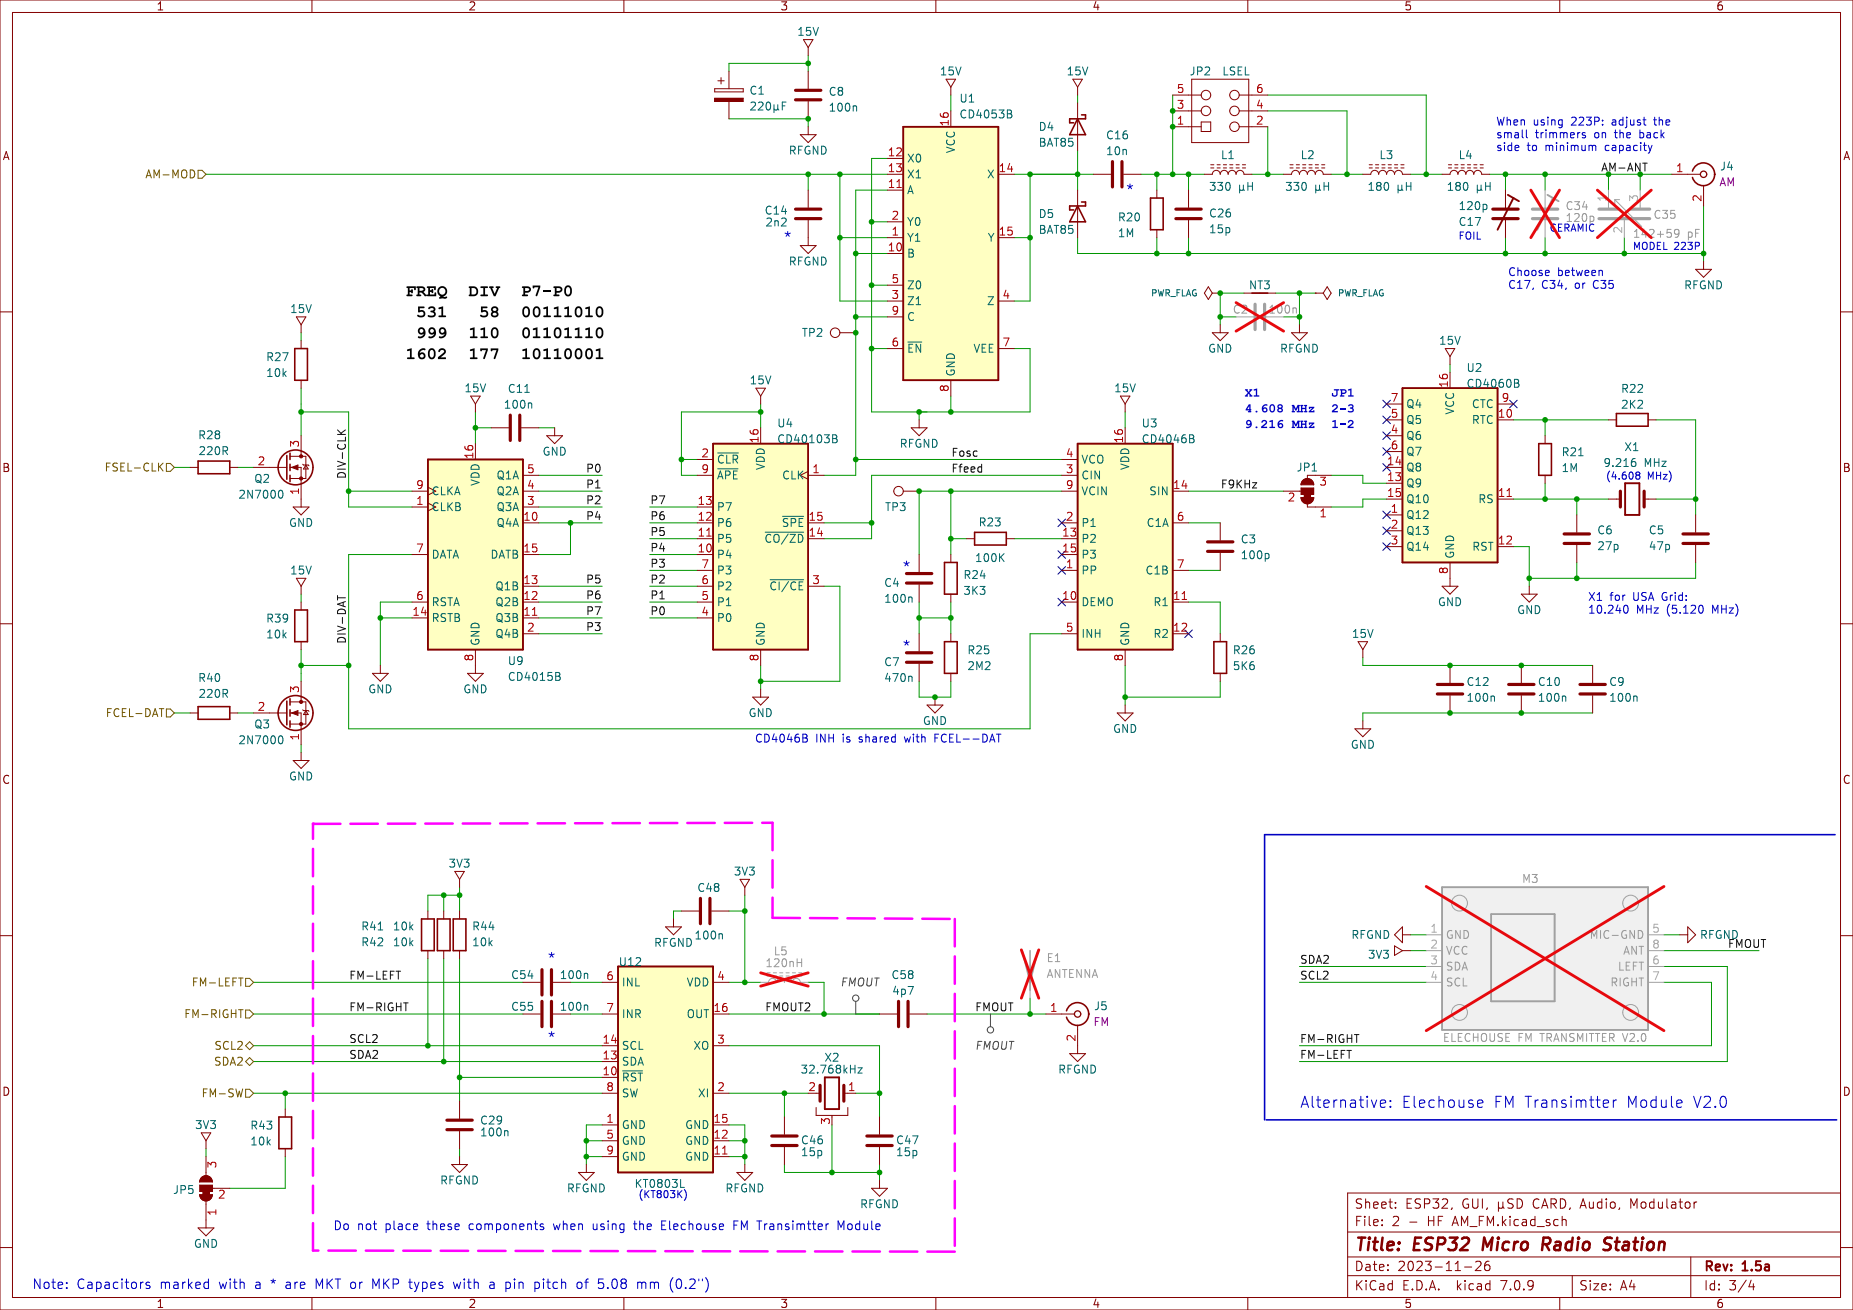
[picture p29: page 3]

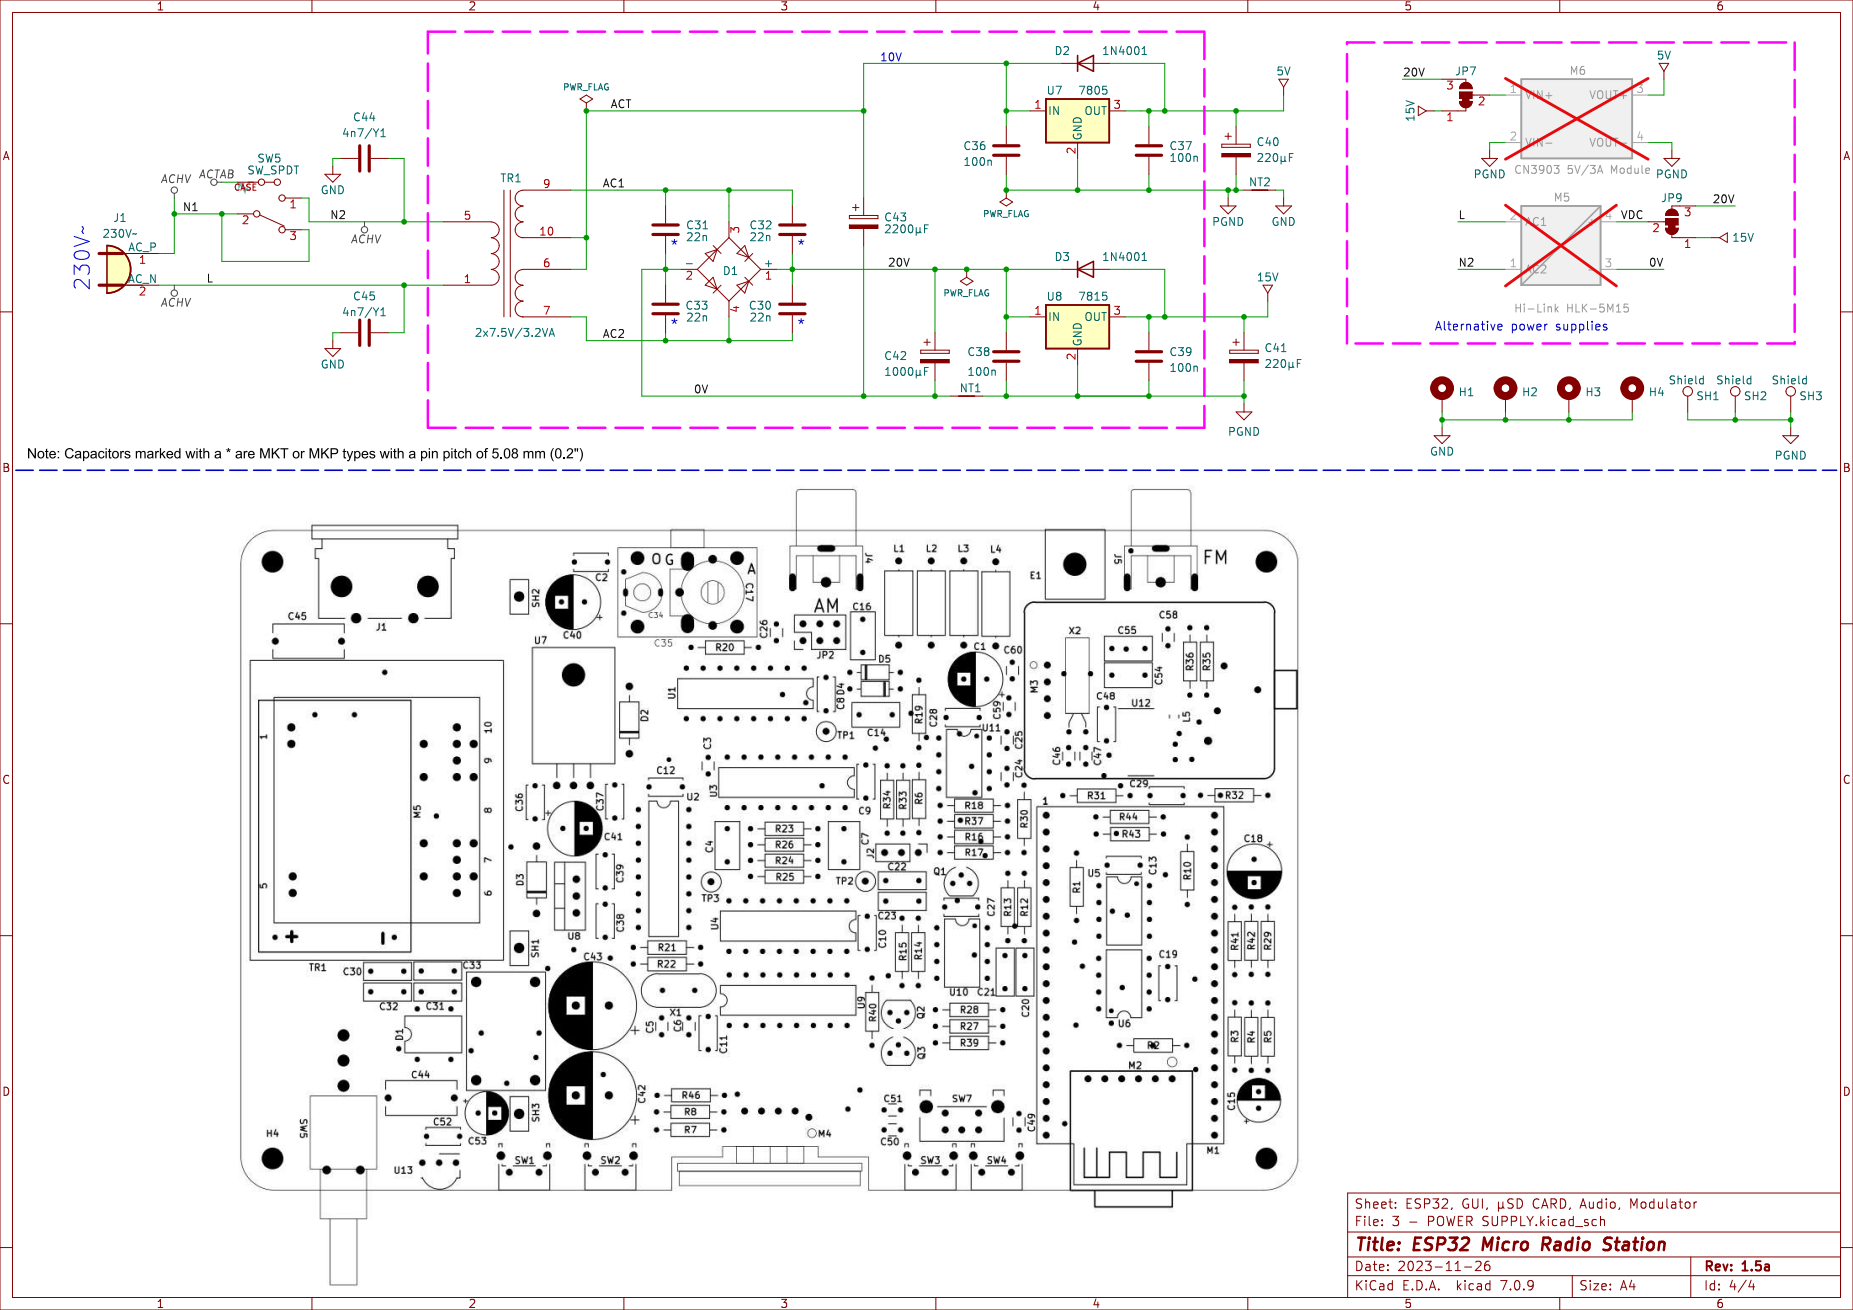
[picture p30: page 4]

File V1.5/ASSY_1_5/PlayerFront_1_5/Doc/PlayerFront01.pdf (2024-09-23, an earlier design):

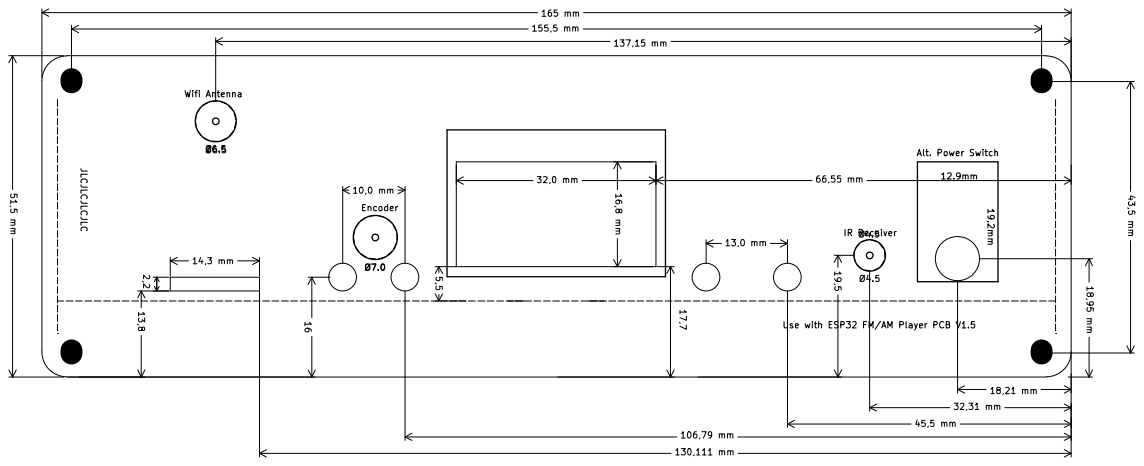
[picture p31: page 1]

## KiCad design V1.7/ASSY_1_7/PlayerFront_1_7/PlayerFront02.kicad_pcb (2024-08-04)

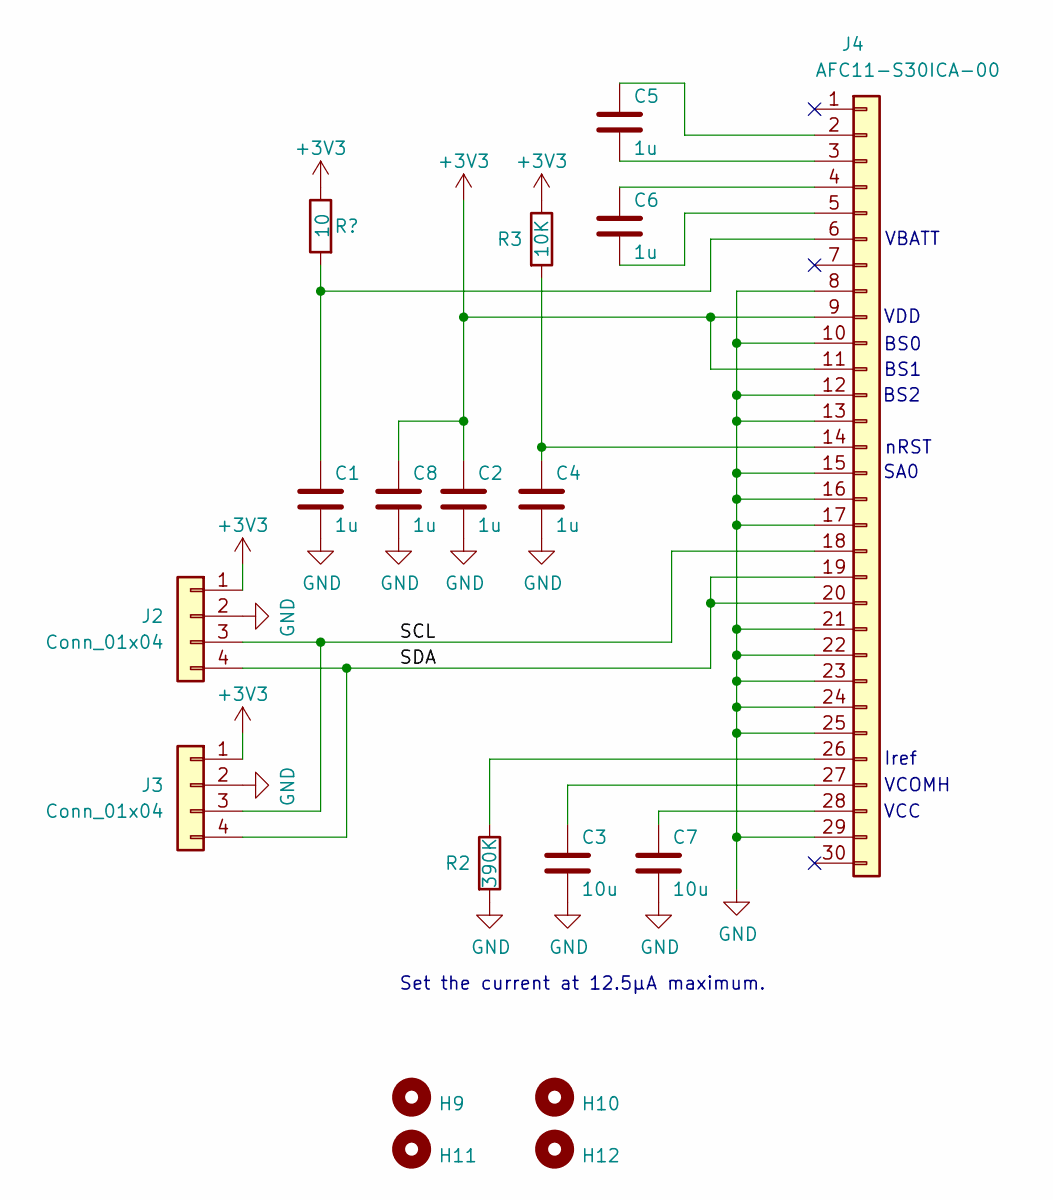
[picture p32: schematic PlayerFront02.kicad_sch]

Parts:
C1, C2, C4, C5, C6, C8: 1u; C_1206_3216Metric_Pad1.33x1.80mm_HandSolder
C3, C7: 10u; C_1206_3216Metric_Pad1.33x1.80mm_HandSolder
H9, H10, H11, H12: MountingHole; MountingHole_3.5mm
J2: Conn_01x04; HeaderMale_1x04_P2.54mm_Vertical_SMD
J3: Conn_01x04; PinHeader_1x04_P2.54mm_Vertical_SMD_Pin1Left
J4: AFC11-S30ICA-00; AFC11-S30ICA-00 FFC FPC Connector 0.5mm Pitch 30 pins VERTI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
R2: 390K; R_1206_3216Metric_Pad1.30x1.75mm_HandSolder; JLC C23150
R3: 10K; R_1206_3216Metric_Pad1.30x1.75mm_HandSolder
R10: 10; R_1206_3216Metric_Pad1.30x1.75mm_HandSolder

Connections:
+3V3: C2.1, C8.1, J2.1, J3.1, J4.9, J4.11, R3.1; also elsewhere on the board
/SCL: J2.3, J3.3, J4.18
/SDA: J2.4, J3.4, J4.19, J4.20
GND: C1.2, C2.2, C3.2, C4.2, C7.2, C8.2, J2.2, J3.2, J4.8, J4.10, J4.12, J4.13, J4.15, J4.16, J4.17, J4.21, J4.22, J4.23, J4.24, J4.25, J4.29, R2.2
unnamed: C5.1, J4.2
unnamed: C5.2, J4.3
unnamed: C6.1, J4.4
unnamed: C6.2, J4.5
unnamed 8: C1.1, J4.6; also elsewhere on the board
unnamed: C4.1, J4.14, R3.2
unnamed: J4.26, R2.1
unnamed: C3.1, J4.27
unnamed: C7.1, J4.28

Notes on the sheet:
Set the current at 12.5μA maximum.
VDD
SA0
BS2
BS0
nRST
Iref
VCOMH
VBATT
VCC
BS1

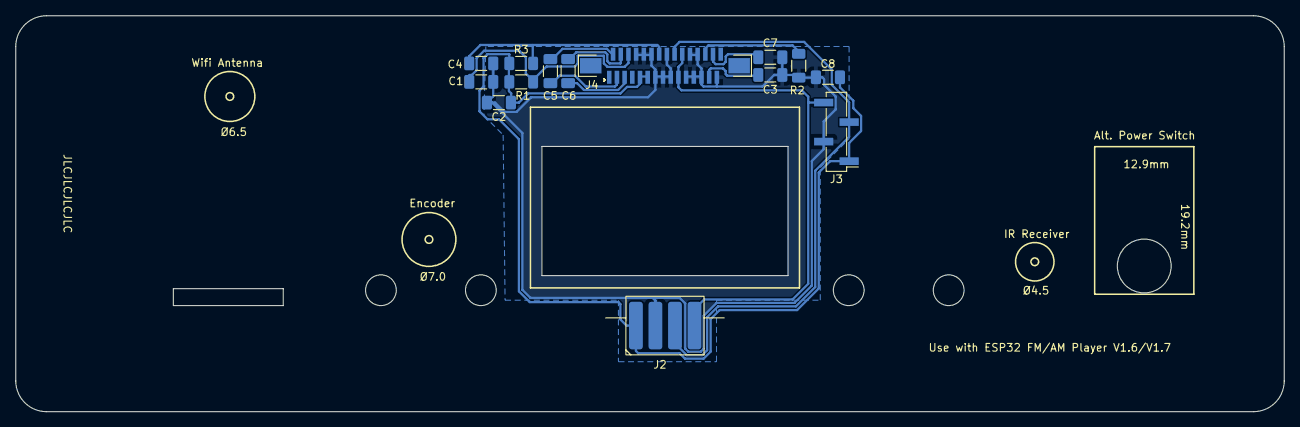
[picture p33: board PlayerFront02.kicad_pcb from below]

Board: 2 copper layers, 165.0 x 51.5 mm, 18 parts (14 on the bottom side), 13 nets.

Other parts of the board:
R1: 10; R_1206_3216Metric_Pad1.30x1.75mm_HandSolder

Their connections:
+3V3: R1.1; also elsewhere on the board
unnamed 8: R1.2; also elsewhere on the board

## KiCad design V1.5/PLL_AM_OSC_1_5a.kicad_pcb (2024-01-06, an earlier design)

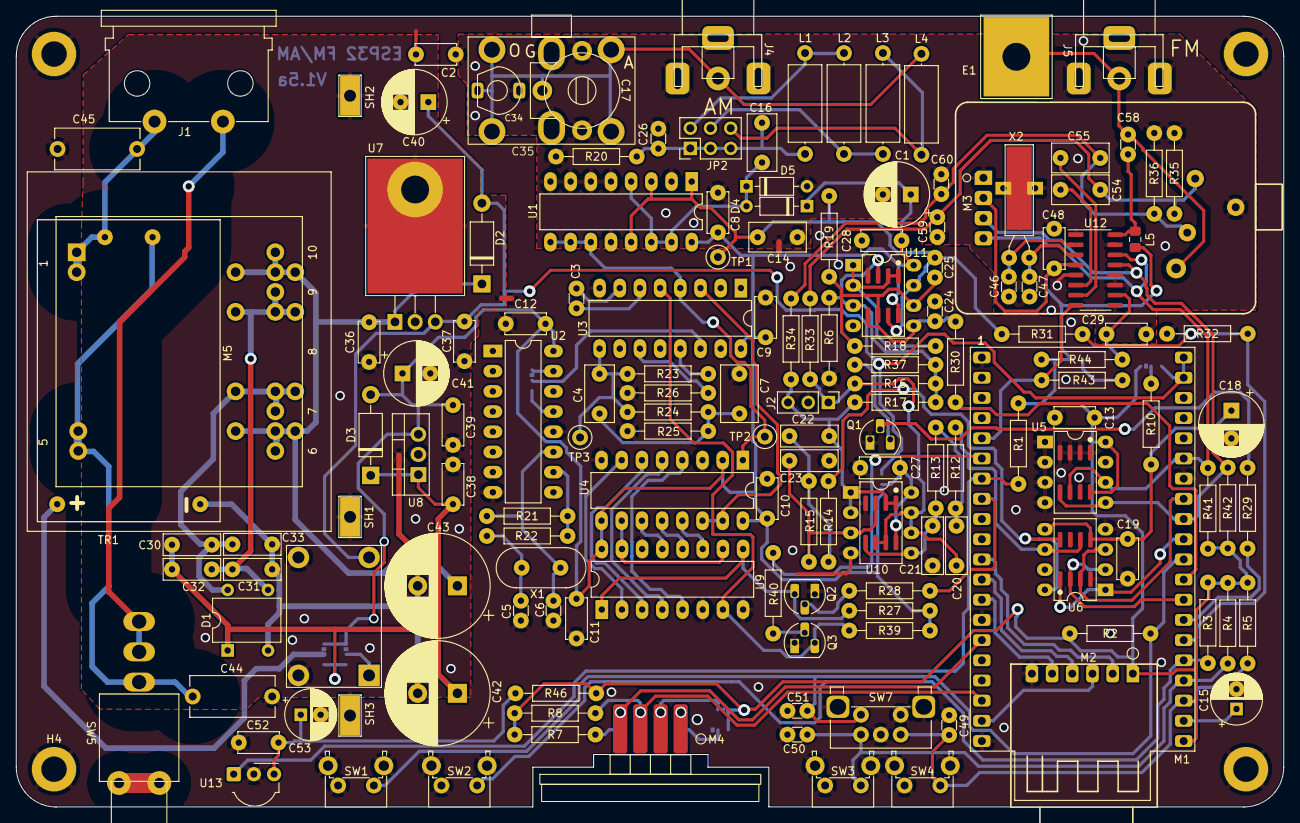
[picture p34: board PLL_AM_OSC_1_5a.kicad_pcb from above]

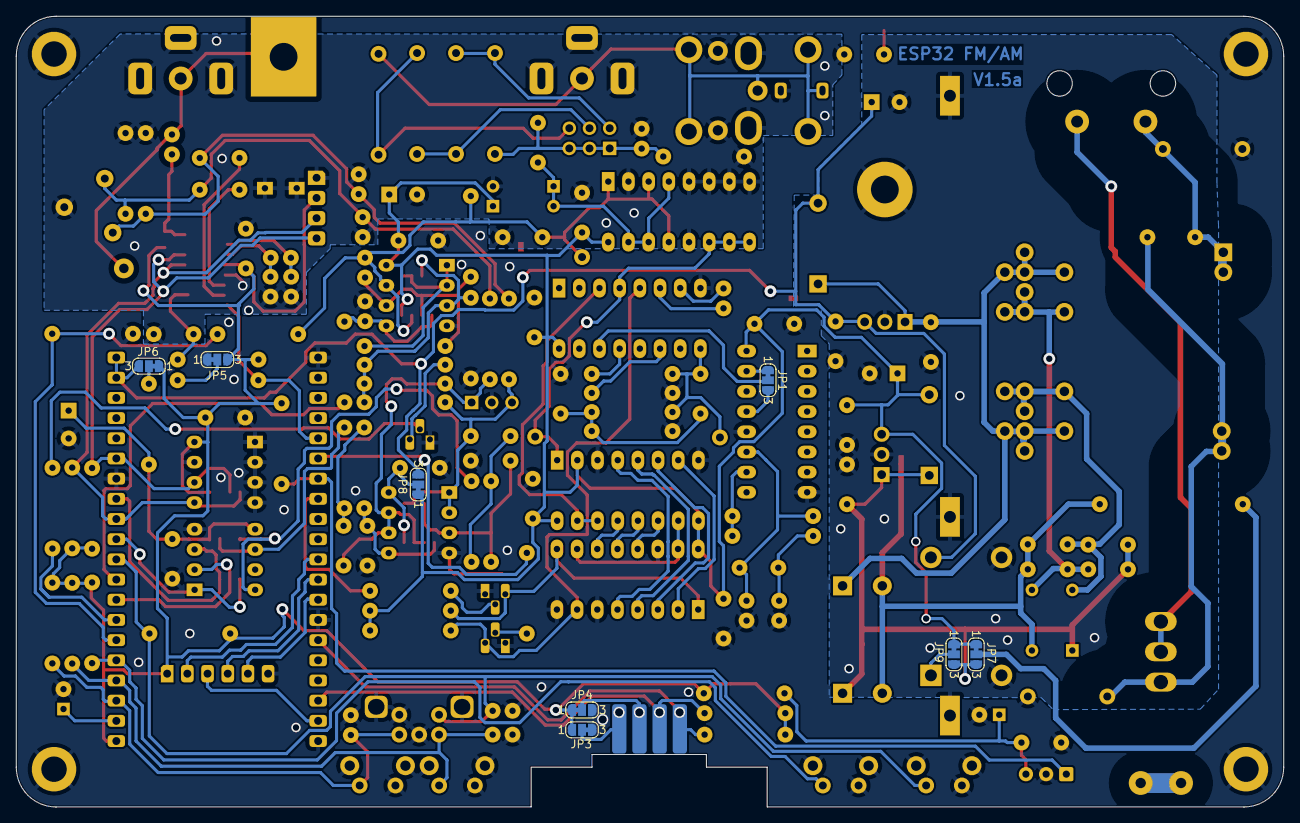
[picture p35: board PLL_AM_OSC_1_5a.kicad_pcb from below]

Board: 2 copper layers, 159.5 x 99.5 mm, 168 parts (8 on the bottom side), 102 nets.

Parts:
C1, C40, C41: 220µF; CE_Radial_D8.0mm_P3.50mm_E2.0mm
C2, C8, C9, C10, C11, C12, C13, C19, C27, C28, C29, C36, C37, C38, C39, C48, C52: 100n; C_CER_D50_W25_P50_E20_H08
C3: 100p; C_CER_D30_W16_P25_E20_H08
C4, C54, C55: 100n; C_MKT_L70_W35_P50__E20_H08
C5, C25: 47p; C_CER_D30_W16_P25_E20_H08
C6: 27p; C_CER_D30_W16_P25_E20_H08
C7: 470n; C_MKT_L70_W45_P50__E20_H08
C14: 2n2; C_MKT_L70_W35_P50__E20_H08
C15: 10µF; CE_Radial_D6.3mm_P2.50mm_E2.0mm
C16: 10n; C_MKT_L70_W35_P50__E20_H08
C17: 120p; GZC18100
C18: 100µF; CE_Radial_D8.0mm_P3.50mm_E2.0mm
C20, C22: 1n; C_MKT_L70_W25_P50__E20_H08
C21, C23: 470p; C_MKT_L70_W25_P50__E20_H08
C24, C49, C50, C51: 10n; C_CER_D30_W16_P25_E20_H08
C26, C46, C47: 15p; C_CER_D30_W16_P25_E20_H08
C30, C31, C32, C33: 22n; C_MKT_L70_W25_P50__E20_H08
C34: 120p; TZ03
C35: 142+59 pF; CAP-VAR-223P-NO-CY
C42: 1000µF; CP_Radial_D13.0mm_P5.00mm
C43: 2200µF; CP_Radial_D13.0mm_P5.00mm
C44, C45: 4n7/Y1; C_Disc_D10.5mm_W5.0mm_P10.00mm
C53: 10u; CE_Radial_D6.3mm_P2.50mm_E2.0mm
C58: 4p7; C_CER_D30_W16_P25_E20_H08
C59, C60: 220p; C_CER_D30_W16_P25_E20_H08
D1: DIL4/1A; Diode_Bridge_DIP-4_W7.62mm_P5.08mm
D2, D3: 1N4001; D_DO-41_SOD81_P10.16mm_Horizontal
D4, D5: BAT85; D_DO-35_SOD27_P7.62mm_Horizontal
E1: ANTENNA; ANTENNA-V3MM5
H1, H2, H3, H4: MountingHole; MountingHole_3.2mm_M3_DIN965_Pad
J1: 230V~; EURO_AC_BX-180
J2: Conn_01x03; PinHeader_1x03_P2.54mm_Vertical
J4, J5: Keystone 900; Keystone RCA
JP1, JP4, JP5, JP6, JP7, JP8, JP9: SolderJumper_3_Bridged12; SolderJumper-3_P1.3mm_Bridged12_RoundedPad1.0x1.5mm_NumberL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
JP2: LSEL; PinHeader_2x03_P2.54mm_Vertical
JP3: SolderJumper_3_Bridged12; SolderJumper-3_P1.3mm_Bridged23_RoundedPad1.0x1.5mm_NumberL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
L1, L2: 330 µH; L_Axial_L9.5mm_D4.0mm_P12.70mm_Horizontal
L3, L4: 180 µH; L_Axial_L9.5mm_D4.0mm_P12.70mm_Horizontal
L5: 120nH; L_0805_2012Metric_Pad1.15x1.40mm_HandSolder
M1: ESP32-WROVER-CAM; ESP32-WROVER-DEV_ON_HEADERS_BARE
M2: µSD CARD MODULE; MOD-USD-ADAPTER18X18
M3: ELECHOUSE FM TRANSMITTER V2.0; MOD-MOD-FM-TRANS-A-ON-HEADERS
M4: OLED-27X27MM; OLED128X64-P4-Card-Edge-dual
M5: Hi-Link HLK-5M15; HiLink_5Mxx
M6: CN3903 5V/3A Module; MOD-DC-DC-DUAL
NT1, NT2, NT3: NetTie_2; NetTie-2_SMD_Pad0.7mm
Q1, Q2, Q3: 2N7000; TO-92_HandSolder
R1, R2, R3, R4, R5, R7, R8, R27, R30, R39, R41, R42, R43, R44: 10k; R_Axial_L6.0mm_D2.0mm_P10.16mm_Horizontal
R6: 100k; R_Axial_L6.0mm_D2.0mm_P10.16mm_Horizontal
R10, R46: 10R; R_Axial_L6.0mm_D2.0mm_P10.16mm_Horizontal
R12, R13, R14, R15, R35, R36: 7k5; R_Axial_L6.0mm_D2.0mm_P10.16mm_Horizontal
R16, R17, R18, R31: 30k; R_Axial_L6.0mm_D2.0mm_P10.16mm_Horizontal
R19: 220K; R_Axial_L6.0mm_D2.0mm_P10.16mm_Horizontal
R20, R21: 1M; R_Axial_L6.0mm_D2.0mm_P10.16mm_Horizontal
R22: 2K2; R_Axial_L6.0mm_D2.0mm_P10.16mm_Horizontal
R23: 100K; R_Axial_L6.0mm_D2.0mm_P10.16mm_Horizontal
R24: 3K3; R_Axial_L6.0mm_D2.0mm_P10.16mm_Horizontal
R25: 2M2; R_Axial_L6.0mm_D2.0mm_P10.16mm_Horizontal
R26: 5K6; R_Axial_L6.0mm_D2.0mm_P10.16mm_Horizontal
R28, R29, R40: 220R; R_Axial_L6.0mm_D2.0mm_P10.16mm_Horizontal
R32: 8k2; R_Axial_L6.0mm_D2.0mm_P10.16mm_Horizontal
R33, R34: 4K7; R_Axial_L6.0mm_D2.0mm_P10.16mm_Horizontal
R37: 15k; R_Axial_L6.0mm_D2.0mm_P10.16mm_Horizontal
SH1, SH2, SH3: Shield; Shielding-pad-2.5x5.0-H1.5
SW1: DOWN; SW_Tactile_SPST_Angled_PTS645Vx83-2LFS
SW2: UP; SW_Tactile_SPST_Angled_PTS645Vx83-2LFS
SW3: PAUSE/OK; SW_Tactile_SPST_Angled_PTS645Vx83-2LFS
SW4: MENU; SW_Tactile_SPST_Angled_PTS645Vx83-2LFS
SW5: SW_SPDT; SWITCH-C&K-7101
SW7: RotaryEncoder_Switch; RotaryEncoder_Bourns_Horizontal_PEC12R-2xxxF-Sxxxx
TP1, TP2, TP3: TestPoint; TestPoint_Loop_D1.80mm_Drill1.0mm_Beaded
TR1: 2x7.5V/3.2VA; Transformer-Tiple-Footprint-38x45
U1: CD4053B; DIP-16_W7.62mm_LongPads
U2: CD4060B; DIP-16_W7.62mm_LongPads
U3: CD4046B; DIP-16_W7.62mm_LongPads
U4: CD40103B; DIP-16_W7.62mm_LongPads
U5: 24LC64; DIP-SO-08_W7.62mm
U6: PT8211; DIP-SO-08_W7.62mm
U7: 7805; TO-220-3_Horizontal_TabDown
U8: 7815; TO-220-3_Vertical
U9: CD4015B; DIP-16_W7.62mm_LongPads
U10, U11: LM358; DIP-SO-08_W7.62mm
U12: KT0803L; SOIC-16_3.9x9.9mm_P1.27mm
U13: TSOP4538; Vishay_MOLD-3Pin
X1: 9.216 MHz; Crystal_HC49-U_Vertical
X2: 32.768kHz; Crystal_AT310_D3.0mm_L10.0mm_Horizontal_1EP_style2

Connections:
/1 - ESP32/ADC: M1.26 (IN35), R31.2, R32.1
/1 - ESP32/AM-DEPTH: M1.27 (IO32), R29.1
/1 - ESP32/AM-MOD: C14.2, C25.2, R19.1, R31.1, TP1.1, U1.1 (Y1), U1.3 (Z1), U1.13 (X1), U11.7
/1 - ESP32/AUD-AM: C25.1, R18.1, R19.2, U11.6 (-)
/1 - ESP32/AUD-L: C20.1, J2.1, R16.2, R33.2, U10.6 (-), U10.7
/1 - ESP32/AUD-R: C22.1, J2.3, R17.2, R34.2, U10.1, U10.2 (-)
/1 - ESP32/BCK: M1.31 (IO27), U6.1 (BCK)
/1 - ESP32/CLK: M1.12 (SCK/IO18), M2.4 (CLK)
/1 - ESP32/CS: M1.11 (SS0/IO5), M2.2 (CS)
/1 - ESP32/DAC1: M1.29 (IO25/DAC1), R30.2
/1 - ESP32/DOUT: M1.33 (IO12¹), U6.3 (DIN)
/1 - ESP32/EN: C15.1, M1.22 (EN/~RST)
/1 - ESP32/FCEL-DAT: M1.6 (SS1/IO2¹), R40.1
/1 - ESP32/FM-SW: M1.5 (IO15²), R43.2, U12.8 (SW)
/1 - ESP32/FSEL-CLK: M1.8 (IO4), R28.1
/1 - ESP32/IR: M1.7 (IO0²), R1.2, U13.1 (OUT)
/1 - ESP32/LCH: R12.2, U6.6 (LCH)
/1 - ESP32/MISO: M1.13 (MISO/IO19), M2.5 (MISO)
/1 - ESP32/MOSI: M1.19 (MOSI/IO23), M2.3 (MOSI)
/1 - ESP32/RCH: R14.2, U6.8 (RCH)
/1 - ESP32/SCL1: M1.18 (SCL/IO22), M4.3 (SCL), R8.2
/1 - ESP32/SCL2: M1.35 (IO13), M3.4 (SCL), R41.2, U5.6 (SCL), U12.14 (SCL)
/1 - ESP32/SDA1: M1.15 (SDA/IO21), M4.4 (SDA), R7.2
/1 - ESP32/SDA2: M1.32 (IO14), M3.3 (SDA), R42.2, U5.5 (SDA), U12.13 (SDA)
/1 - ESP32/SW1: C51.1, M1.30 (IO26/DAC2), R2.2, SW1.1, SW7.S1
/1 - ESP32/SW2: M1.25 (IN34), R3.2, SW2.1
/1 - ESP32/SW3: C50.1, M1.24 (IN39/SVN), R4.2, SW3.1, SW7.A
/1 - ESP32/SW4: C49.1, M1.23 (IN36/SVP), R5.2, SW4.1, SW7.B
/1 - ESP32/WS: M1.28 (IO33), U6.2 (WS)
/2 - HF AM_FM/AM-ANT: C17.1, C34.1, C35.1, C35.3, J4.1 (In), L4.1
/2 - HF AM_FM/DIV-CLK: Q2.3 (D), R27.1, U9.1 (CLKB), U9.9 (CLKA)
/2 - HF AM_FM/DIV-DAT: Q3.3 (D), R39.1, U3.5 (INH), U9.7 (DATA)
/2 - HF AM_FM/F9KHz: JP1.2 (C), U3.14 (SIN)
/2 - HF AM_FM/FM-LEFT: C54.1, C59.1, M3.6 (LEFT), R33.1, R35.1
/2 - HF AM_FM/FM-RIGHT: C55.1, C60.1, M3.7 (RIGHT), R34.1, R36.1
/2 - HF AM_FM/FMOUT: C58.2, E1.1 (A), J5.1 (In), M3.8 (ANT)
/2 - HF AM_FM/FMOUT2: C58.1, L5.2, U12.16 (OUT)
/2 - HF AM_FM/Ffeed: U3.3 (CIN), U4.14 (~CO/ZD), U4.15 (~SPE)
/2 - HF AM_FM/Fosc: TP2.1, U1.9 (C), U1.10 (B), U1.11 (A), U3.4 (VCO), U4.1 (CLK)
/2 - HF AM_FM/P0: U4.4 (P0), U9.5 (Q1A)
/2 - HF AM_FM/P1: U4.5 (P1), U9.4 (Q2A)
/2 - HF AM_FM/P2: U4.6 (P2), U9.3 (Q3A)
/2 - HF AM_FM/P3: U4.7 (P3), U9.2 (Q4B)
/2 - HF AM_FM/P4: U4.10 (P4), U9.10 (Q4A), U9.15 (DATB)
/2 - HF AM_FM/P5: U4.11 (P5), U9.13 (Q1B)
/2 - HF AM_FM/P6: U4.12 (P6), U9.12 (Q2B)
/2 - HF AM_FM/P7: U4.13 (P7), U9.11 (Q3B)
/3 - POWER SUPPLY/0V: C31.2, C33.2, C42.2, C43.2, D1.2 (-), M5.3 (-), NT1.1
/3 - POWER SUPPLY/20V: C30.2, C32.2, C38.1, C42.1, D1.1 (+), D3.1 (K), JP7.3 (B), JP9.3 (B), U8.1 (IN)
/3 - POWER SUPPLY/AC1: C31.1, C32.1, D1.3, TR1.9 (SC)
/3 - POWER SUPPLY/AC2: C30.1, C33.1, D1.4, TR1.7 (SB)
/3 - POWER SUPPLY/ACT: C36.1, C43.1, D2.1 (K), TR1.6 (SA), TR1.10 (SD), U7.1 (IN)
/3 - POWER SUPPLY/L: C45.2, J1.2 (AC_N), M5.2 (AC1), TR1.1 (AA)
/3 - POWER SUPPLY/N1: J1.1 (AC_P), SW5.2 (B), SW5.3 (A)
/3 - POWER SUPPLY/N2: C44.2, M5.1 (AC2), SW5.1 (C), TR1.5 (AB)
/3 - POWER SUPPLY/VDC: JP9.2 (C), M5.4 (+)
GND: C2.2, C5.2, C6.2, C7.1, C9.1, C10.1, C11.1, C12.1, C13.2, C15.2, C18.2, C19.2, C21.2, C23.2, C24.2, C27.2, C28.2, C44.1, C45.1, C49.2, C50.2, C51.2, C52.2, C53.2, H1.1, H2.1, H3.1, H4.1, J2.2, JP3.3 (B), JP4.3 (B), JP5.1 (A), M1.1 (GND), M1.14 (GND), M1.20 (GND), M1.34 (GND), M2.6 (GND), NT2.2, NT3.1, Q1.1 (S), Q2.1 (S), Q3.1 (S), R6.2, R25.1, R26.1, R32.2, SW1.2, SW1.H, SW2.2, SW2.H, SW3.2, SW3.H, SW4.2, SW4.H, SW7.C, SW7.MP, SW7.S2, U2.8 (GND), U2.12 (RST), U3.8 (GND), U4.3 (~CI/CE), U4.8 (GND), U5.1 (A0), U5.2 (A1), U5.3 (A2), U5.4 (GND), U5.7 (WP), U6.4 (GND), U9.6 (RSTA), U9.8 (GND), U9.14 (RSTB), U10.4 (V-), U11.4 (V-), U13.2 (GND)
GND1: C36.2, C37.2, C38.2, C39.2, C40.2, C41.2, M6.2 (VIN-), M6.4 (VOUT-), NT1.2, NT2.1, SH1.1, SH2.1, SH3.1, U7.2 (GND), U8.2 (GND)
unnamed: C4.1, C7.2, R24.1, R25.2
unnamed: C5.1, R22.1, X1.1
unnamed: C16.1, C26.1, JP2.1, JP2.3, JP2.5, L1.2, R20.1
unnamed: C20.2, R12.1, R13.2
unnamed: C22.2, R14.1, R15.2
unnamed: C16.2, D4.2 (A), D5.1 (K), U1.4 (Z), U1.14 (X), U1.15 (Y)
unnamed: JP1.1 (A), U2.15 (Q10)
unnamed: JP1.3 (B), U2.13 (Q9)
unnamed: JP2.2, L1.1, L2.1
unnamed: JP2.4, L2.2, L3.2
unnamed: JP2.6, L3.1, L4.2
unnamed: JP3.2 (C), M4.1 (GND)
unnamed: JP4.2 (C), M4.2 (VCC)
unnamed: JP5.2 (C), R43.1
unnamed: JP6.2 (C), R10.1
unnamed: JP7.2 (C), M6.1 (VIN+)
unnamed: C27.1, JP8.2 (C), U10.8 (V+)
unnamed: Q1.3 (D), R37.1
unnamed: Q1.2 (G), R29.2
unnamed: Q2.2 (G), R28.2
unnamed: Q3.2 (G), R40.2
unnamed: C6.1, R21.1, U2.11 (RS), X1.2
unnamed: R21.2, R22.2, U2.10 (RTC)
unnamed: C3.2, U3.6 (C1A)
unnamed: C3.1, U3.7 (C1B)
unnamed: R23.2, U3.13 (P2)
unnamed: R26.2, U3.11 (R1)
unnamed: C4.2, R23.1, R24.2, TP3.1, U3.9 (VCIN)
unnamed: C23.1, R15.1, U10.3 (+)
unnamed: C21.1, R13.1, U10.5 (+)
unnamed: R6.1, R16.1, R17.1, R37.2, U11.3 (+)
unnamed: R18.2, U11.1, U11.2 (-)
unnamed: C24.1, R30.1, U11.5 (+)
unnamed: C54.2, U12.6 (INL)
unnamed: C55.2, U12.7 (INR)
unnamed: C46.1, U12.2 (XI), X2.2
unnamed: C47.1, U12.3 (XO), X2.1
unnamed: C29.1, R44.2, U12.10 (~RST)
unnamed: C52.1, C53.1, R46.2, U13.3 (Vs)
RFGND: C1.2, C2.1, C8.1, C14.1, C17.2, C26.2, C29.2, C34.2, C35.2, C46.2, C47.2, C48.1, C59.2, C60.2, D5.2 (A), J4.2 (Ext), J5.2 (Ext), M3.1 (GND), M3.5 (MIC-GND), NT3.2, R20.2, R35.2, R36.2, U1.2 (Y0), U1.5 (Z0), U1.6 (~EN), U1.7 (VEE), U1.8 (GND), U1.12 (X0), U12.1 (GND), U12.5 (GND), U12.9 (GND), U12.11 (GND), U12.12 (GND), U12.15 (GND), X2.3
V3.3: C13.1, C48.2, JP3.1 (A), JP4.1 (A), JP5.3 (B), JP6.1 (A), L5.1, M1.21 (3V3), M2.1 (VDD), M3.2 (VCC), R1.1, R2.1, R3.1, R4.1, R5.1, R7.1, R8.1, R41.1, R42.1, R44.1, R46.1, U5.8 (VCC), U12.4 (VDD)
V5: C37.1, C40.1, D2.2 (A), JP6.3 (B), JP8.3 (B), M1.39 (5V), M1.40 (5V), M6.3 (VOUT+), U7.3 (OUT)
V15: C1.1, C8.2, C9.2, C10.2, C11.2, C12.2, C28.1, C39.1, C41.1, D3.2 (A), D4.1 (K), JP7.1 (A), JP8.1 (A), JP9.1 (A), R27.2, R39.2, U1.16 (VCC), U2.16 (VCC), U3.16 (VDD), U4.2 (~CLR), U4.9 (~APE), U4.16 (VDD), U8.3 (OUT), U9.16 (VDD), U11.8 (V+)
VDDdac: C18.1, C19.1, R10.2, U6.5 (VDD)

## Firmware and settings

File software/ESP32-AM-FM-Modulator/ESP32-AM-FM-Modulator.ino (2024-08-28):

// Increase size:
// https://github.com/espressif/arduino-esp32/issues/1906

#include <esp_idf_version.h>

#if (ESP_IDF_VERSION < ESP_IDF_VERSION_VAL(4, 0, 0)) || (ESP_IDF_VERSION >= ESP_IDF_VERSION_VAL(5, 0, 0))
  #error Cannot be built with version 1.0.6 or older or version 3.0.0 or newer
#endif

#include <driver/dac.h>

#include "src/AudioI2S/Audio.h"
#include "src/OneButton/OneButton.h"
#include "src/Hardware/board.h"
#include "src/settings.h"
#include "src/ChipInfo.h" 
#include "src/I2C_Scanner.h"
#include "ESP32CompositeVideo.h"

#include "Player.h"
#include "Display.h"
#include "SimpleWaveGenerator.h"
#include "Gui.h"

SettingsClass      Settings(Wire1,I2C_LOW_CLOCK_SPEED);
KT0803X_Class      KT0803X(Wire1, PIN_FM_SW, I2C_LOW_CLOCK_SPEED);
MC44BS373CA_Class  MC44BS373CA(Wire1,I2C_LOW_CLOCK_SPEED);
ESP32CompositeVideo_Class ESP32CompositeVideo(Wire1,I2C_LOW_CLOCK_SPEED);

SsidSettingsClass  SsidSettings;
UrlSettingsClass   UrlSettings;
TrackSettingsClass TrackSettings;

PlayerClass        Player;
DisplayClass       Display;

SimpleWaveGeneratorClass WaveGenerator;

#define BLUETOOTH_FILE_NAME "bluetooth.ini"
#define SSID_FILE_NAME      "ssid.ini"
#define WEBRADIO_FILE_NAME  "webradio.ini"

OneButton SW1(PIN_SW1);
OneButton SW2(PIN_SW2);
OneButton SW3(PIN_SW3);
OneButton SW4(PIN_SW4);
OneButton SW5(PIN_SW5);

//=====================================================================
//== Locals: Set AM Modulator
//=====================================================================

static void SetAmModLevel(bool update_pin = true) {
  dac_output_enable(DAC_CHANNEL_1); // Need to re-init DAC every time alfer I2S change
  dac_output_voltage(DAC_CHANNEL_1, Settings.NV.AmModLevel ? Settings.AmOffset50 : Settings.AmOffset100 - Settings.NV.AmTrim);
  if(update_pin) {
    digitalWrite(PIN_AM_DEPTH, Settings.NV.AmModLevel ? 1 : 0);
    DEBUG_MSG_VAL("AM modulation depth set to %d%%\n", Settings.NV.AmModLevel ? 50 : 100);
  }
}

static void SetAmDivider(void) {
  uint8_t AM_ON = Settings.NV.OutputSel & SET_OUTPUT_AM_MASK;
  int divider = Settings.NV.FreqAM / Settings.GridStep() - 1;
  CD4015B_WriteByte(divider, AM_ON, 0); 
  DEBUG_MSG_VAL4("AM PLL Divider %d (0x%02X), frequency %d, inh %d\n", divider, divider, Settings.NV.FreqAM, AM_ON);
}

static void SetOutputSel(void) {
  SetAmDivider();
  
  if(Settings.NV.OutputSel & SET_OUTPUT_FM_MASK) {
    DEBUG_MSG("FM Modulator On\n");
    //digitalWrite(PIN_FM_SW, 1);
    if(!KT0803X.Start(0)) {
      DEBUG_MSG("FM Modulator Error\n");
      Settings.FmPresent = 0;
      if(Settings.NV.OutputSel & SET_OUTPUT_TV_MASK)
        Settings.NV.OutputSel = SET_OUTPUT_TV_MASK | SET_OUTPUT_AM_MASK;
      else
        Settings.NV.OutputSel = SET_OUTPUT_AM_MASK;
      //digitalWrite(PIN_FM_SW, 0);
    }
  }
  else {
    DEBUG_MSG("FM Modulator Off\n");
    KT0803X.Stop();
    //digitalWrite(PIN_FM_SW, 0);
  }
  //MC44BS373CA.SetSound(Settings.NV.xxxx, 0);
  MC44BS373CA.SetRfOff(!(Settings.NV.OutputSel & SET_OUTPUT_TV_MASK), 0); 
  MC44BS373CA.SetChannel(Settings.NV.TvChannel, 1);
}
//#define DEBUG_CALCULATE_AM_MOD_OFFSETS

#define MOD_OFFSET_LOW_THRESHOLD     16  // Note: ADC kicks in on at about 0.1 volts, so we need to tune a bit, with Settings.NV.AmTrim
//#define MOD_OFFSET_HIGH_THRESHOLD  3300  // see: https://randomnerdtutorials.com/esp32-adc-analog-read-arduino-ide/
#define MOD_OFFSET_HIGH_THRESHOLD  2700  // temp threshold, needs different value on final PCBA
#define DELAY_WAVE()  delayMicroseconds(80)  

static void CalculateAmModOffsets(void) {
  int adc  = 0;
  #ifdef DEBUG_CALCULATE_AM_MOD_OFFSETS
    int a[256];
  #endif 
  int16_t dac;
    
  PT8211_Init(); // Reassign the pins for bit banged I2S
  Settings.AmOffset100 = UINT16_MAX;
  // Calculate for 100% depth
  digitalWrite(PIN_AM_OFF, LOW); 
  digitalWrite(PIN_AM_DEPTH, LOW); 
  PT8211_Write(INT16_MAX, INT16_MAX);
  dac_output_enable(DAC_CHANNEL_1);   // Need to re-init DAC every time alfer I2S change
  dac_output_voltage(DAC_CHANNEL_1, 0);
  delay(1); // Check C24 if delay doesn't work (C24 must be 10nF and not 100nF)
  #ifdef DEBUG_CALCULATE_AM_MOD_OFFSETS
  for(dac = 0; dac < 256; dac++) {
  #else
  for(dac = 0; dac < 256 && Settings.AmOffset100 == UINT16_MAX; dac++) {
  #endif
    dac_output_voltage(DAC_CHANNEL_1, dac);
    DELAY_WAVE(); 
    #ifdef DEBUG_CALCULATE_AM_MOD_OFFSETS
      a[dac] = 
    #endif
    adc = analogRead(PIN_ADC);
    if(Settings.AmOffset100 == UINT16_MAX && adc >= MOD_OFFSET_LOW_THRESHOLD)
      Settings.AmOffset100 = dac;// - Settings.NV.AmTrim;
  }
  #ifdef DEBUG_CALCULATE_AM_MOD_OFFSETS
  Serial.println("");
  for(dac = 0; dac < 256; dac += 8) {
    Serial.printf("Seed: %3i, ADC: ", dac);
    for(int i = 0; i < 8; i++)
      Serial.printf("%4i  ", a[dac+i]);
    Serial.println("");
  }
  #endif
  Serial.printf("\nOffset for 100%% depth: %i\n", Settings.AmOffset100);
   
  // Calculate for to 50% depth
  Settings.AmOffset50 = UINT16_MAX;
  digitalWrite(PIN_AM_DEPTH, HIGH);  
  PT8211_Write(INT16_MIN, INT16_MIN);
  dac_output_voltage(DAC_CHANNEL_1, 0);
  delay(1); 
  #ifdef DEBUG_CALCULATE_AM_MOD_OFFSETS
  for(dac = 0; dac < 256; dac++) {
  #else
  for(dac = 0; dac < 256 && Settings.AmOffset50 == UINT16_MAX; dac++) {
  #endif
    dac_output_voltage(DAC_CHANNEL_1, dac);
    DELAY_WAVE(); 
    #ifdef DEBUG_CALCULATE_AM_MOD_OFFSETS
      a[dac] = 
    #endif
    adc = analogRead(PIN_ADC);
    if(Settings.AmOffset50 == UINT16_MAX && adc >= MOD_OFFSET_HIGH_THRESHOLD)
      Settings.AmOffset50 = dac;
  }
  digitalWrite(PIN_AM_DEPTH, 0);
  #ifdef DEBUG_CALCULATE_AM_MOD_OFFSETS
  Serial.println("");
  for(dac = 0; dac < 256; dac += 8) {
    Serial.printf("Seed: %3i, ADC: ", dac);
    for(int i = 0; i < 8; i++)
      Serial.printf("%4i  ", a[dac+i]);
    Serial.println("");
  }
  #endif
  Serial.printf("Offset for  50%% depth: %i\n", Settings.AmOffset50);
}

static void SetFmGainAndFreq(void) {
  KT0803X.SetFreq(Settings.NV.FreqFM, false);
  KT0803X.SetPga(Settings.NV.FmPga, false); 
  KT0803X.SetMono(Settings.NV.FmModType, true);
}

static void SetTvChannel(void) {
  MC44BS373CA.NewChannel(Settings.NV.TvChannel, 1);
  MC44BS373CA.ShowInfo();
}

static void PrintWifiInfo() {
  char s[64];
   //WiFi.printDiag(Serial);
   sprintf(s, "WiFi TX level: %d (max %d = %sdB)", WiFi.getTxPower(), Settings.GetWifiTxLevel(), Settings.GetWifiTxLevelDB());
  Serial.println(s);
}

void SetWifiPower(int pwr, bool force = false) {
  if(!force && (pwr < 0 || pwr == Settings.NV.WifiTxIndex || pwr > SET_WIFI_TX_MAX)) {
    pwr = Settings.NV.WifiTxIndex;
    Serial.print("Wifi TX Power stays at ");
  }
  else {
    Settings.NV.WifiTxIndex = pwr;
    Serial.print("Changing Wifi TX Power to ");
    if (Settings.NV.SourceAF == SET_SOURCE_WEB_RADIO)
      WiFi.setTxPower((wifi_power_t)Settings.GetWifiTxLevel());
  }
  Serial.printf("entry %d (value %d = %sdB)\n",pwr, Settings.GetWifiTxLevel(), Settings.GetWifiTxLevelDB());
}

//=====================================================================//
//== Local: serial_command parser (for debugging purposes)           ==//
//=====================================================================//

static struct {
  const char * shortname;
  const char * longname;
  bool suppress_help;
} serial_command_list[] = {
  { "?",      "help"            , false }, // 0
  { "s",      "settings"        , false }, // 1
  { "rl",     "radiolist"       , false }, // 2
  { "rlr",    "radiolistraw"    , false }, // 3
  { "ssid",   "ssid"            , false }, // 4
  { "ssidpw", "ssidpassword"    , true  }, // 5
  { "tl",     "tracklist"       , false }, // 6
  { "pi",     "playinfo"        , false }, // 7
  { "sd",     "sd-card"         , false }, // 8
  { "wr",     "webradio"        , false }, // 9
  { "wf",     "waveform"        , false }, // 10
  { "bt",     "bluetooth"       , false }, // 11
  { "res",    "softreset"       , false }, // 12
  { "pw",     "printwaveform"   , false }, // 13
  { "pwh",    "printwaveformhex", false }, // 14
  { "sys",    "systeminfo"      , false }, // 15
  { "oled",   "oled-display"    , false }, // 16
  { "wifi",   "wifi-status"     , false }, // 17
  { "tx",     "wifi-tx-power"   , false }, // 18
  { "vol",    "volume"          , true  }, // 19
};

static void serial_command_help(void) {
  Serial.println("Short   | Long");
  Serial.println("--------|-------------");
  for (int i = 0; i < sizeof(serial_command_list) / sizeof(serial_command_list[0]); i++)
    if (!serial_command_list[i].suppress_help)
      Serial.printf("%-8s| %s\n", serial_command_list[i].shortname, serial_command_list[i].longname);
}

static int find_command_match(String &r) {
  for(int i = sizeof(serial_command_list) / sizeof(serial_command_list[0]) - 1; i >= 0 ; i--) {
    if(r.startsWith(serial_command_list[i].shortname) || r.startsWith(serial_command_list[i].longname)) {
      int len = r.indexOf(' ');
      if(len > 0) 
        r = r.substring(len + 1);
      return i;
    }
  }
  return -1;
}

static void change_player(uint8_t old_id, uint8_t new_id);

static void parse_command(String &r) { 
  r.trim();
  r.toLowerCase();
  int len = r.indexOf(' ');
  Serial.print("SERIAL COMMAND: ");
  Serial.println(r);
  switch(find_command_match(r)) {
    case  0: serial_command_help();     break;
    case  1: Settings.Print();          break;
    case  2: UrlSettings.Print(false);  break;
    case  3: UrlSettings.Print(true);   break;
    case  4: SsidSettings.Print(false); break;
    case  5: SsidSettings.Print(true);  break;
    case  6: TrackSettings.Print();     break;
    case  7: Player.SD_PrintDebug();    break;
    case  8: change_player(Settings.GetCurrentSourceId(), SET_SOURCE_SD_CARD);   break;
    case  9: change_player(Settings.GetCurrentSourceId(), SET_SOURCE_WEB_RADIO); break;
    case 10: change_player(Settings.GetCurrentSourceId(), SET_SOURCE_WAVE_GEN);  break;
    case 11: change_player(Settings.GetCurrentSourceId(), SET_SOURCE_BLUETOOTH); break;
    case 12: Settings.doSoftRestart();    break;
    case 13: Player.WP_PrintDebug(false); break;
    case 14: Player.WP_PrintDebug(true);  break;
    case 15: PrintChipInfo(0x0F);         break;
    case 16: OLED.Print();                break;
    case 17: PrintWifiInfo();             break;
    case 18: SetWifiPower(r.toInt());     break;
    case 19: { int vol = r.toInt();
               if(vol > 0)
                 Player.SetVolume(vol);
             }
             break;
    default: Serial.println("Unknown Command"); break;
  }
}

//=====================================================================
//== Local: Timestamps
//=====================================================================

class TimeStampClass {
  public:
    TimeStampClass();
    void Update(void);
    uint32_t GetStamp10ms(void) { return timestamp_10ms;    }
    uint32_t GetStamp1sec(void) { return timestamp_1sec;    } 
    bool     Get10msTick(void)  { return ten_ms_tick;       }
    bool     GetSecondTick()    { return second_tick;       }
    bool     Get4SecTick()      { return four_seconds_tick; }
  private:
    uint64_t timestamp_us_prev;
    uint16_t timestamp_1sec_cnt;
    uint32_t timestamp_10ms;
    uint32_t timestamp_1sec;
    bool     ten_ms_tick;
    bool     second_tick;
    bool     four_seconds_tick;
};

TimeStampClass::TimeStampClass() {
  timestamp_10ms          = 0;
  timestamp_1sec          = 0;
  ten_ms_tick             = false;
  second_tick             = false;
  four_seconds_tick       = false;
  timestamp_us_prev       = 0;
  timestamp_1sec_cnt      = 0;
}

void TimeStampClass::Update(void) {
  uint64_t timestamp_us = esp_timer_get_time();
  ten_ms_tick             = false;
  second_tick             = false;
  four_seconds_tick       = false;
  if(timestamp_us - timestamp_us_prev >= TIMESTAMP_10MS_DIV) {
    timestamp_10ms++;
    timestamp_1sec_cnt++;
    timestamp_us_prev += TIMESTAMP_10MS_DIV;
    if(timestamp_us - timestamp_us_prev < TIMESTAMP_10MS_DIV) // supress multiple ticks 
      ten_ms_tick = true; 
    if(timestamp_1sec_cnt == 100) {
      timestamp_1sec++;
      timestamp_1sec_cnt = 0;
      second_tick = true;
      four_seconds_tick = !(timestamp_1sec & 3);
    }
  }
}

TimeStampClass TimeStamps;

//=====================================================================//
//== Local: Read setup and track data from SD Card                   ==//
//=====================================================================//

static bool ReadSetupFromCard(bool get_init_data = true) {
  if(Settings.NV.SourceAF == SET_SOURCE_WAVE_GEN) return true; // Nothing to load for waveform player
  if (!SD.begin(PIN_VSPI_SS, SPI, SPI_SD_SPEED)) {
    Serial.println("Card Mount Failed, using SSID & Radio lists from EEPROM");
    Settings.NoCard = 1;
    return false;
  }
  Serial.println("Card Mount Succeeded");
  Settings.NoCard = 0;
  switch(Settings.NV.SourceAF) {
    case SET_SOURCE_SD_CARD   : TrackSettings.LoadFromCard();
                                break;
    case SET_SOURCE_WEB_RADIO : if(!SsidSettings.LoadFromCard(SSID_FILE_NAME))
                                  Serial.println("Using SSID list from EEPROM");
                                if(!UrlSettings.LoadFromCard(WEBRADIO_FILE_NAME))
                                  Serial.println("Using web station list from EEPROM");
                                break;
    case SET_SOURCE_BLUETOOTH : if(!Settings.LoadFromCard(BLUETOOTH_FILE_NAME))
                                  Serial.println("Using Bluetooth ID from EEPROM");
                                break;
  }
  SD.end(); // webradio doesn't like a mounted SD Card
  return true;
}

//=====================================================================//
//== Local: change player                                            ==//
//=====================================================================//

static void change_player(uint8_t old_id, uint8_t new_id) {
  if(new_id != old_id) {
    Serial.print("Change Player from \"");
    Serial.print(Settings.GetSourceName(old_id));
    Serial.print("\" to \"");
    Serial.print(Settings.GetSourceName(new_id));
    Serial.println("\"");
    Player.Stop();
    Settings.Play = 0;
    Settings.NV.SourceAF = new_id;
    Display.ShowBaseScreen(DISPLAY_HELP_PLEASE_WAIT);
    delay(100); // Give threads in Stop() some time to die out properly
    Settings.doSoftRestart();
  }
}

static void change_player(bool prev) {
  uint8_t CurrentSourceId = Settings.GetCurrentSourceId();
  if(prev) Settings.PrevPlayer();
  else     Settings.NextPlayer();
  change_player(CurrentSourceId, Settings.GetCurrentSourceId());
}

//=====================================================================//
//== Local: Loop function for Settings (keeps audio running)         ==//
//=====================================================================//

void SettingsLoopFunction(void) { Player.loop(); }

//=====================================================================//
//== Local: Button handlers                                          ==//
//=====================================================================//

static void GUI_Handler(uint8_t key) {
  if(key != 0xFF) Serial.printf("Button %d pressed: ", key);
  switch(GuiCallback(key/*, TimeStamps.GetStamp10ms()*/)) {
    case GUI_RESULT_NEW_TRACK      : Player.PlayNew();      break;
    case GUI_RESULT_NEXT_PLAY      : Player.PlayNext();     break;
    case GUI_RESULT_PREV_PLAY      : Player.PlayPrevious(); break;
    case GUI_RESULT_PAUSE_PLAY     : if(Settings.FirstTime) {
                                       Serial.println("FIRST TIME");    
                                       Settings.FirstSong = 1;
                                       Player.Play();
                                       Settings.FirstTime = 0;
                                     }
                                     else
                                       Player.PauseResume();
                                     break;
    case GUI_RESULT_SEEK_PLAY      : Player.PositionEntry(); break;
    //case GUI_RESULT_STOP_PLAY    : break;
    //case GUI_RESULT_START_PLAY   : break;
    case GUI_RESULT_NEW_SSID       : Player.NewSsid(); break;
    case GUI_RESULT_NEW_AM_FREQ    : SetAmDivider();     Display.ShowFrequencies(); break;
    case GUI_RESULT_NEW_FM_FREQ    : SetFmGainAndFreq(); Display.ShowFrequencies(); break;
    case GUI_RESULT_NEW_TV_CHANNEL : SetTvChannel();     Display.ShowFrequencies(); break;
    case GUI_RESULT_NEW_OUTPUT_SEL : SetOutputSel();     Display.ShowFrequencies(); break;
    case GUI_RESULT_NEW_AF_SOURCE  : change_player(Settings.NV.SourceAF, Settings.NewSourceAF); break;
    case GUI_RESULT_NEW_AM_TRIM    : SetAmModLevel(false); break;
    case GUI_RESULT_NEW_AM_DEPTH   : SetAmModLevel(true);  break;
    case GUI_RESULT_NEW_FM_MOD_TYPE:
    case GUI_RESULT_NEW_FM_PGA     : SetFmGainAndFreq(); break;
    case GUI_RESULT_NEW_VID_IMAGE  : ESP32CompositeVideo.ShowImage(Settings.NV.VidImage); break;
    case GUI_RESULT_NEW_WIFI_TX_LEVEL : SetWifiPower(Settings.NV.WifiTxIndex, true); break;
    case GUI_RESULT_NEW_BT_TX_LEVEL   : /*SetBtPower(Settings.NV.BtTxIndex, true);*/ break;
    default: break;
  }
  if(key != 0xFF) Serial.println();
}

static void SW1_HandleClick(void) { GUI_Handler(KEY_MENU); } // GUI_Handler(KEY_SPARE); }
static void SW2_HandleClick(void) { GUI_Handler(KEY_DN);   }
static void SW3_HandleClick(void) { GUI_Handler(KEY_UP);   }
static void SW4_HandleClick(void) { GUI_Handler(KEY_OK);   }
static void SW5_HandleClick(void) { GUI_Handler(KEY_MENU); }

//=====================================================================//
//== Local: Housekeeping, fix things that might go wrong in time     ==//
//=====================================================================//

static void Housekeeping(void) {
  //Serial.print("Houskeeping: ");
  // MC44BS373CA is very sensitive to power glitches, so rewrite registers init every four seconds
  MC44BS373CA.Init(1, 0);
  // ESP32CompositeVideo may start up too slow, check if present now
  if(!Settings.VidPresent) {
    ESP32CompositeVideo.Init(0);
    Settings.VidPresent = ESP32CompositeVideo.ChipPresent();
    if(Settings.VidPresent) {
      Serial.println("(Re)discovered ESP32 Composite Video module. ");
      if(Settings.NV.VidImage >= ESP32CompositeVideo.ImageCount())
        Settings.NV.VidImage = 0;
      ESP32CompositeVideo.ShowImage(Settings.NV.VidImage);
    }
  }
  //Serial.println("Done.");
}

//=====================================================================//
//== Main Set-up                                                     ==//
//=====================================================================//
//
// It appears that switching to another player cannot be done dynamically.
// Some parts of the player seems not to be cleaned up properly, so the new
// player will not work, or is unstable. Therefore, the solution is to do a
// soft restart to assure the player get a fresh end clean environment.
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
void loop(void) {
  static unsigned run_time = 0;

  TimeStamps.Update();
  if(TimeStamps.GetSecondTick()) {
    Settings.EepromStore();
    if(Settings.InitDAC) { // Some audio drivers destroys the DAC, so reinit if necessary
      SetAmModLevel();
      Settings.InitDAC = 0;
    }
  }
  if(TimeStamps.Get4SecTick()) { 
    Housekeeping();
  }

  Player.loop(TimeStamps.Get10msTick(), TimeStamps.GetSecondTick()); // runs also audio.loop() if applicable
  //Button logic
  SW1.tick();
  SW2.tick();
  SW3.tick();
  SW4.tick();
  SW5.tick();
  GUI_Handler(KEY_NONE);
  //Serial port commands
  if (Serial.available()) {
    String r = Serial.readStringUntil('\n');
    parse_command(r);
  }
}

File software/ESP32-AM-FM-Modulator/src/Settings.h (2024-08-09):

#ifndef _SETTINGS_H_
#define _SETTINGS_H_

#include <stdint.h>
#include <Wire.h>
#include <SD.h>

//=======================================================
// EEPROM specification
//=======================================================

#define BT_DEVICE_NAME   "ESP32 AM/FM Transmitter"

#define EEPROM_TYPE      64 // 24Cxx where xx is EEPROM_SIZE
#define EEPROM_PAGE_SIZE 32 // in bytes, check datasheet for value

#if EEPROM_TYPE <= 16
  #define EEPROM_I2C_ADDRESS_SIZE     1  // 1 for 24C02 through 24C16
#else
  #define EEPROM_I2C_ADDRESS_SIZE     2  // 2 for 24C32 and larger
#endif

#if EEPROM_TYPE == 0
  #define EEPROM_SIZE        64
  #define EEPROM_BLOCK_SIZE  64
#elsif EEPROM_TYPE == 1
  #define EEPROM_SIZE       128
  #define EEPROM_BLOCK_SIZE 128
#else
  #define EEPROM_SIZE (256 * EEPROM_TYPE / 2)
  #if EEPROM_I2C_ADDRESS_SIZE == 1
    #define EEPROM_BLOCK_SIZE 256
  #else
    #define EEPROM_BLOCK_SIZE EEPROM_SIZE
  #endif

#endif

#define EEPROM_I2C_DEVICE         0x50
#define EEPROM_I2C_CLOCK_SPEED  100000  // Most EEPROMs work only at 100kHz

#define EEPROM_SETTINGS_PAGE         0
#define EEPROM_SETTINGS_ADDR         0

//=======================================================
// Main settings
//   - NV stored in EEPROM page 0 @ 0x00-0x7F
//   - Make sure sizeof(NV) stays below 128
//=======================================================

#define SET_SOURCE_MIN            0
#define SET_SOURCE_MAX            3

#define SET_SOURCE_SD_CARD        0
#define SET_SOURCE_WEB_RADIO      1
#define SET_SOURCE_WAVE_GEN       2
#define SET_SOURCE_BLUETOOTH      3
#define SET_SOURCE_DEFAULT        SET_SOURCE_SD_CARD

#define SET_WAVE_FORM_MIN         0
#define SET_WAVE_FORM_MAX         4 //3: only waveforms, 4: plus DAC test, 6: plus DAC debug
#define SET_WAVE_SINE_440HZ       0
#define SET_WAVE_SINE_1KHZ        1
#define SET_WAVE_TRI_440HZ        2
#define SET_WAVE_TRI_1KHZ         3
#define SET_WAVE_DEFAULT          SET_WAVE_SINE_440HZ

#define SET_OUTPUT_MIN            1 // AM only
#define SET_OUTPUT_MAX            5 // With FM and TV chips mounted
#define SET_OUTPUT_AM_ONLY        1
#define SET_OUTPUT_FM_ONLY        2
#define SET_OUTPUT_AM_FM          3
#define SET_OUTPUT_TV_ONLY        4
#define SET_OUTPUT_AM_TV          5
#define SET_OUTPUT_FM_TV          6  // not used: FM & TV interfere
#define SET_OUTPUT_ALL            7  // not used: FM & TV interfere
#define SET_OUTPUT_DEFAULT        SET_OUTPUT_ALL
#define SET_OUTPUT_AM_MASK        0x1  // bit0
#define SET_OUTPUT_FM_MASK        0x2  // bit1
#define SET_OUTPUT_TV_MASK        0x4  // bit2

#define SET_AMGRID_MAX            2
#define SET_AMGRID_EUR            0
#define SET_AMGRID_AUS            1
#define SET_AMGRID_USA            2
#define SET_AMGRID_DEFAULT        SET_AMGRID_EUR

#define SET_AM_MOD_LEVEL_100      0
#define SET_AM_MOD_LEVEL_50       1
#define SET_AM_MOD_LEVEL_DEFAULT  SET_AM_MOD_LEVEL_100

#define SET_AM_MOD_TRIM_MIN       0
#define SET_AM_MOD_TRIM_MAX       20
#define SET_AM_MOD_TRIM_DEFAULT   7

#define SET_FM_MOD_STEREO         0
#define SET_FM_MOD_MONO           1
#define SET_FM_MOD_DEFAULT        SET_FM_MOD_STEREO

#define SET_FM_PGA_MIN            0
#define SET_FM_PGA_MAX            31
#define SET_FM_PGA_DEFAULT        0

#define SET_AM_FREQ_MIN_EUR       531  // European BC band
#define SET_AM_FREQ_MAX_EUR      1602
#define SET_AM_FREQ_STEP_EUR        9  // European grid = 9 kHz

#define SET_AM_FREQ_MIN_AUS       531  // Australia/New Zealand BC band
#define SET_AM_FREQ_MAX_AUS      1701
#define SET_AM_FREQ_STEP_AUS        9

#define SET_AM_FREQ_MIN_USA       530  // American BC Band
#define SET_AM_FREQ_MAX_USA      1700
#define SET_AM_FREQ_STEP_USA       10

#define SET_AM_FREQ_DEFAULT       990  // 990 kHz (valid in all grids)

#define SET_FM_FREQ_MIN           875  // 87.5 to 108.0 MHz
#define SET_FM_FREQ_MAX          1080
#define SET_FM_FREQ_STEP            1
#define SET_FM_FREQ_DEFAULT       999  // 99.9 MHz

#define SET_TV_CHAN_MIN             2
#define SET_TV_CHAN_MAX            69
#define SET_TV_CHAN_DEFAULT         6

#define SET_VHF_CHAN_MIN            2
#define SET_VHF_CHAN_MAX           12
#define SET_VHFI_CHAN_MAX           4
#define SET_VHFII_CHAN_MIN          5
#define SET_VHFI_FREQ_MIN        4825  // in kHz * 10
#define SET_VHFII_FREQ_MIN      17525  // in kHz * 10
#define SET_VHF_FREQ_STEP         700  // in kHz * 10

#define SET_UHF_CHAN_MIN           21
#define SET_UHF_CHAN_MAX           69
#define SET_UHF_FREQ_MIN        47125  // in kHz * 10
#define SET_UHF_FREQ_STEP         800  // in kHz * 10

#define SET_SSID_MAX               3  //max 4 networks

#define SET_WIFI_TX_MAX            9  // max wifi tx level (index)
#define SET_WIFI_TX_DEFAULT        0  // Points to highest level

#define SET_BT_TX_MAX              7  // max bluetooth tx level (index)
#define SET_BT_TX_DEFAULT          5  // +3dbm
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

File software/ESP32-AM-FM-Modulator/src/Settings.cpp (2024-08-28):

#include <arduino.h>
#include <Wire.h>
#include <WiFi.h>
#include <stdlib.h>
#include "Settings.h"
#include "Version.h"
#include "Hardware/board.h"

#define NvData        ((unsigned char *)&NV)
#define NvMirrorData  ((unsigned char *)&NvMirror)


#if EEPROM_I2C_ADDRESS_SIZE == 1
  #error THIS APPLICATION ACCEPS ONLY EEPROMS >= 32K
#endif

const char * const s_not_printable = "[Not Printable]";
const char * const s_none          = "[None]";

const uint8_t wifi_power_table[SET_WIFI_TX_MAX + 1] = {
  WIFI_POWER_19_5dBm,       // 78
  72, //WIFI_POWER_19dBm,   // 76 actual WIFI_POWER_18dBm = 72
  66, //WIFI_POWER_18_5dBm, // 74 actual WIFI_POWER_16_5dBm = 66
  //WIFI_POWER_17dBm,       // 68
  WIFI_POWER_15dBm,         // 60
  WIFI_POWER_13dBm,         // 52
  WIFI_POWER_11dBm,         // 44
  WIFI_POWER_8_5dBm,        // 34
  WIFI_POWER_7dBm,          // 28
  WIFI_POWER_5dBm,          // 20
  WIFI_POWER_2dBm,          // 8
};

//=======================================================
// Helper functions
//=======================================================

static int SD_read_line(File &f, char * dest, int n) {
  memset(dest, 0, n);

  // See: https://stackoverflow.com/questions/65621607/read-line-by-line-in-file-and-store-into-string-flash-data-saving-spiffs
  int len = f.readBytesUntil('\n', dest, n);
  if (len && dest[len - 1] == '\r')
    dest[--len] = '\0'; // If a '\r' is present, remove it!
  return len;
}

#if 1
static void HEXR(uint8_t s[], int n) {
  for(int i = 0; i < n; i++)
    Serial.printf("%02X",s[i]);
  Serial.println();
}
#else
  #define HEXR(a,b)
#endif

#if 0
static void HEXP(uint8_t s[], int n) {
  for(int i = 0; i < n; i++)
    Serial.printf("%02X",s[i]);
  Serial.println();
}
#else
  #define HEXP(a,b)
#endif

inline static int Validate(int val, int min, int max, int def) {
  if(val < min || val > max)
    return def;
  return val;
}
inline static int Validate(int val, int min, int max) {
  if(val < min)
    return max;
  if (val > max)
    return min;
  return val;
}

TwoWire & EEPROM_I2C_PORT(void) { return *Settings._wire; }

#define WIRE EEPROM_I2C_PORT()

static void Read24Cxx(int addr, uint8_t * dat, int len) {
#if EEPROM_I2C_ADDRESS_SIZE == 2 // Only for 24C32 and larger
  WIRE.beginTransmission(EEPROM_I2C_DEVICE);
  WIRE.write(addr >> 8);
  WIRE.write(addr & 0xFF);
  if( WIRE.endTransmission() != 0) return;
  for(int i = 0; i < len; i+= 64) {
    if(len-i >= 64) {
       WIRE.requestFrom(EEPROM_I2C_DEVICE, 64, (int)(len-i == 64));
       WIRE.readBytes(&dat[i], 64);
    }
    else {
      WIRE.requestFrom(EEPROM_I2C_DEVICE, len-i, 1);
      WIRE.readBytes(&dat[i], len-i);
    }
  }
#endif
}

static void Read24Cxx(int page, int addr, uint8_t * dat, int len) {
#if EEPROM_I2C_ADDRESS_SIZE == 1
  WIRE.beginTransmission(EEPROM_I2C_DEVICE | (page & 7));
  WIRE.write(addr);
  if(WIRE.endTransmission() != 0) return;
  WIRE.requestFrom(EEPROM_I2C_DEVICE| (page & 7), len, 1);
  WIRE.readBytes(dat, len);
#else
  WIRE.beginTransmission(EEPROM_I2C_DEVICE);
  WIRE.write(page);
  WIRE.write(addr);
  if(WIRE.endTransmission() != 0) return;
  WIRE.requestFrom(EEPROM_I2C_DEVICE, len, 1);
  WIRE.readBytes(dat, len);
#endif
}

static void Write24Cxx(int page, int addr, uint8_t dat) {
  #if EEPROM_I2C_ADDRESS_SIZE == 1
    WIRE.beginTransmission(EEPROM_I2C_DEVICE | (page & 7));
  #else
    WIRE.beginTransmission(EEPROM_I2C_DEVICE);
    WIRE.write(page);
  #endif
  WIRE.write(addr);
  WIRE.write(dat);
  if(WIRE.endTransmission() != 0) return;
  delay(5);
}

static void Write24CxxPage(uint16_t addr, uint8_t * dat) {
  addr /= EEPROM_PAGE_SIZE; // Place on page boundary
  addr *= EEPROM_PAGE_SIZE;
  DEBUG_MSG_VAL("Writing EEPROM page at 0x%04X : ", addr);
  HEXR(dat, EEPROM_PAGE_SIZE);

  #if EEPROM_I2C_ADDRESS_SIZE == 1
    WIRE.beginTransmission(EEPROM_I2C_DEVICE | ((addr >> 8) & 7));
  #else
    WIRE.beginTransmission(EEPROM_I2C_DEVICE);
    WIRE.write(addr >> 8);
  #endif
  WIRE.write(addr & 0xFF);
  WIRE.write(dat, EEPROM_PAGE_SIZE);
  if(WIRE.endTransmission() != 0) return;
  delay(5);
}

// Write each byte individually. Optimizing is possible, but then you must consider the
// page size of the EEPROM. Page size could be 8,16,32,64,128 bytes. See datasheet for info.
static void Write24Cxx(int page, int addr, uint8_t * dat, int len) {
  for(int i = 0; i < len; i++)
    Write24Cxx(page, addr+i, dat[i]);
}

//==============================================================================
// Main settings
//   - NV stored in EEPROM page 0 @ 0x00-0x7F
//============================================================================== 

uint8_t SettingsClass::GridStep(void) {
  return NV.GridAM == SET_AMGRID_USA ? SET_AM_FREQ_STEP_USA : SET_AM_FREQ_STEP_EUR;
}
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

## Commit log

2024-01-03 Create production
    Gerbers
2024-06-23 Delete software/ESP32-AM-FM-Modulator/src/Board.h
    Moved to directory "Hardware"
2024-06-23 Delete software/ESP32-AM-FM-Modulator/src/CD4015B.cpp
    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
2024-06-23 Delete software/ESP32-AM-FM-Modulator/src/CD4015B.h
    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
2024-06-23 Delete software/ESP32-AM-FM-Modulator/src/KT0803X.cpp
    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
2024-06-23 Delete software/ESP32-AM-FM-Modulator/src/KT0803X.h
    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
2024-06-23 Delete software/ESP32-AM-FM-Modulator/src/NFOR_SSD1306.cpp
    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
2024-06-23 Delete software/ESP32-AM-FM-Modulator/src/NFOR_SSD1306.h
    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
2024-06-23 Delete software/ESP32-AM-FM-Modulator/src/NFOR_SSD1306_fonts.cpp
    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
2024-06-23 Delete software/ESP32-AM-FM-Modulator/src/NFOR_SSD1306_fonts.h
    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
2024-06-23 Delete software/ESP32-AM-FM-Modulator/src/PT8211.cpp
    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
2024-06-23 Delete software/ESP32-AM-FM-Modulator/src/PT8211.h
    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
2024-06-25 Update build instructions
    Added instructions about board package
2024-07-06 Prepared for compilation with Arduino ESP32 3.0.x
2024-07-20 Update and rename 1 - ESP32.kicad_sch to V1.5/1 - ESP32.kicad_sch
    [1 - ESP32.kicad_sch]
2024-07-20 Update and rename 2 - HF AM_FM.kicad_sch to V1.5/2 - HF AM_FM.kicad_sch
    [2 - HF AM_FM.kicad_sch]
2024-07-20 Update and rename 3 - POWER SUPPLY.kicad_sch to V1.5/3 - POWER SUPPLY.kicad_sch
    [3 - POWER SUPPLY.kicad_sch]
2024-07-20 Update and rename PLL_AM_OSC_1_5a.kicad_sch to V1.5/PLL_AM_OSC_1_5a.kicad_sch
    [PLL_AM_OSC_1_5a.kicad_sch]
2024-07-21 Add files via upload
    Something went wrong moving the files to V1.5. Uploaded again.
    [PLL_AM_OSC_1_5a.kicad_pcb]
2024-07-28 Add files via upload
    This is the (unverified) design of the front panel for the V1.5 PCBA. For using this design,
    you have to install the 1.3 inch OLED display on the PCBA. if you want to use the 0.96 inch
    OLED display, you have to modify the viewing opening.
    [1455T2202-base-100mm.STEP, 1455T2202-top-100mm.STEP, PLL_AM_OSC_1_5_ASSY.kicad_pcb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]
2024-08-04 Adjusted mounting holes
    Made mounting holes a bit oval, to enable tiny positional adjustments.
2024-08-28 Fixed initialisation error in SimpleWaveGenerator
    [Board.h, Display.cpp, ESP32-AM-FM-Modulator.ino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]
2024-10-04 Improved track and url selection
    Tracks and URLs can now be selected by name, rather than by number
